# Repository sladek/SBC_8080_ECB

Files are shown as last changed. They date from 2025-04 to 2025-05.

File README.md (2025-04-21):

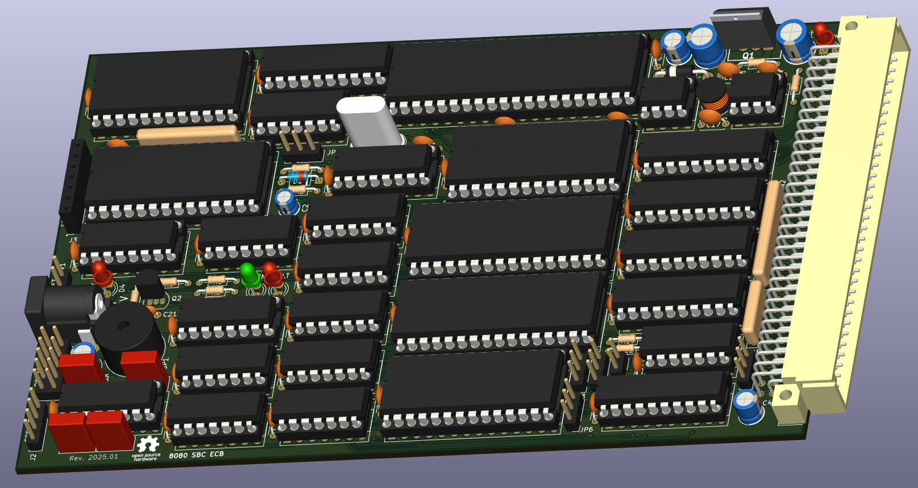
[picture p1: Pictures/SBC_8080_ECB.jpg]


## SBC 8080 ECB microcomputer

This is my attempt to build a single-board microcomputer based on the Intel 8080 CPU. It contains the following features:

- Extended 512k x 8-bit SRAM that can be fully accessed via paging.

- 128 x 8-bit FLASH EPROM that is accessible after RESET so it can contain a bootloader, which can be moved to SRAM and boot the operating system or monitor program.

- Programmable Interrupt Controller Intel 8259.

- Programmable Interval Timer Intel 8253, which is used for baud rate generation and can also generate an interrupt and be connected to the speaker.

- Universal Synchronous/Asynchronous Receiver/Transmitter (USART) Intel 8251 used as serial console so SBC can be accessed directly via RS232 interface.

- ECB bus interface, which can be used for microcomputer extensions. The ECB bus interface facilitates communication between the main processor and various peripheral devices, enabling system expansion and enhancing functionality. Additionally, it allows for the integration of specialized hardware components, which can further optimize performance and adaptability in various applications. History of ECB bus is described below.

- Voltage power supply for CPU: +5V, -5V, +12V which follows the requirement that -5V must be the first voltage present. It also contains inverter for -5V generation and a boost converter from 5V to 12V so the SBC can be powered only from one +5V power supply.

Here you can find a schematics for the SBC. Kicad files are also available in this repository. 
[SBC_8080_ECB schematics.](Documentation/SBC_8080_ECB_.pdf)

## ECB bus history

(https://www.retrobrewcomputers.org/doku.php?id=boards:ecb:start)

Below is an image depicting the latest definition of the ECB bus as utilized by the RetroBrew Computers group. It also addresses issues related to the /RESET and /RESOUT pin definitions and the solutions implemented. This design incorporates a 3-pin jumper header to allow for the selection of the appropriate configuration.

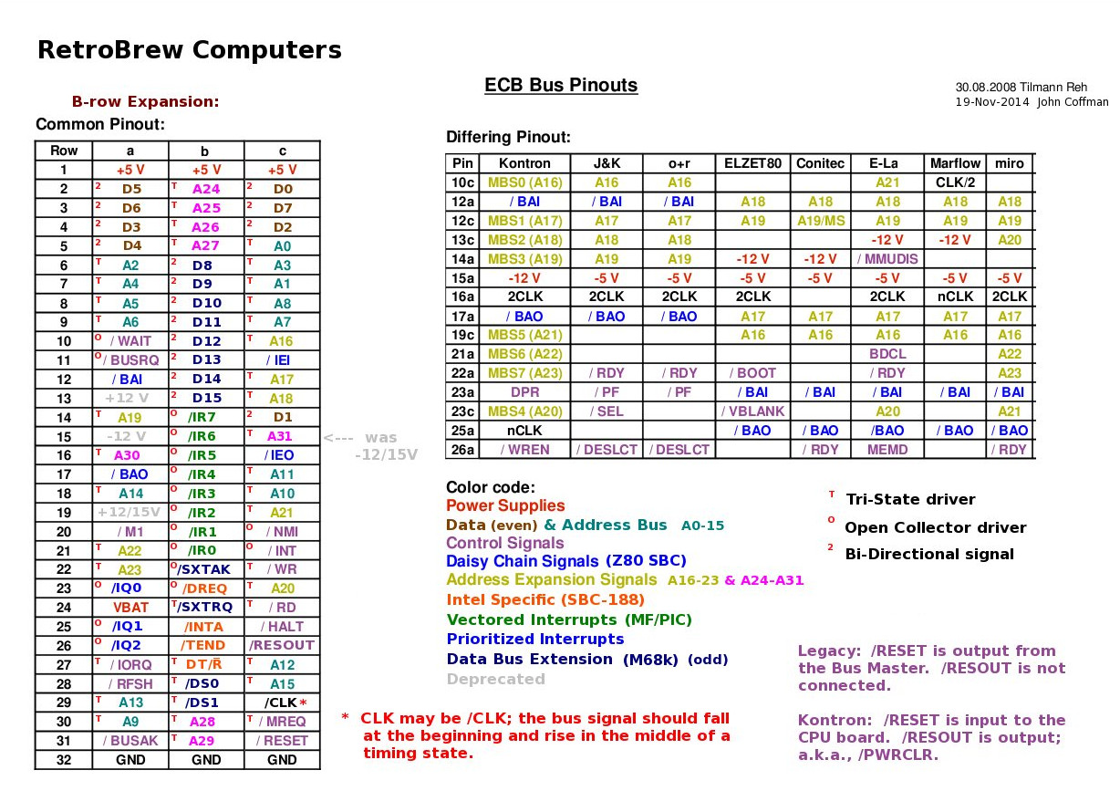
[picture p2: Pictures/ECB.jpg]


The German firm Kontron defined what is believed to be the earliest bus using the 96-pin DIN 41612 EuroCard connectors. The bus for their Z80 offering used only the A-row and C-row pins; the B-row was left entirely unused to allow for the use of 64-pin connectors in the 96-pin format.

The earliest known RetroBrew bus definition included B-row pin definitions to facilitate the anticipated expansion of the Z80 bus to other processors, particularly Intel. To this day, the ECB SBC v2 (Z80) does not use the B-row pins.

One error occurred in defining the first RetroBrew bus: confusion between signals RESET (C-31) and RESOUT (C-26). The error resulted in a bad guess at what Kontron's intentions were with these two signals. SBC v1 (Z80) used RESET as an output from the CPU board to peripheral boards and did not use the RESOUT signal at all. Peripheral boards were designed with this assumption. When it was pointed out several years ago (I am unsure of the date) that Kontron's intention was for RESET to be an input to the CPU board only and that the CPU board would then put out a signal, RESOUT, to all of the peripheral boards in the system.

The resolution to the above mistake is that all the newer CPU and peripheral boards have a reset selection jumper to select which RetroBrew reset convention is to be used. Look for a 3-pin jumper header: shorting pins 1-2 indicates the older, erroneous, reset convention for use with older boards; shorting pins 2-3 indicates the use of the Kontron convention. The Kontron convention is essential if RESET is to be received from any of the ECB backplanes, and only newer boards are allowed in such a system. Old CPU boards have a 2-pin Reset (in) connection as well as a reset switch right on the CPU card.

## Generate baud rate for 8251

### Response:

The **8253 Programmable Interval Timer (PIT)** can be used as a **baud rate generator** for serial communication by generating clock pulses at the required frequency. This is done by programming one of its three counters to divide an input clock signal down to the desired baud rate.

### Steps to Use 8253 as Baud Rate Generator

1. **Select the Counter:** 
   The 8253 has three counters (Counter 0, Counter 1, Counter 2). You need to choose one for generating the baud rate.

2. **Provide the Clock Input:**
   
   The 8253 typically receives a clock input (e.g., **1.8432 MHz or some
   other standard clock frequency**). Ensure the clock is stable and properly connected.

3. **Calculate the Divider Value:**  
   The baud rate is generated by dividing the input clock using a counter. The formula is:
   
    Input Frequency RateDivider=Baud RateClock Input Frequency
   
   For example, if the input clock is **1.8432 MHz** and you need a baud rate of **9600**,
   the divider value is:
   
   1843200÷9600=192

4. **Program the 8253:**
   
   - Load the
     appropriate **mode** (typically Mode 2 – Rate Generator or Mode 3 – Square Wave).
   
   - Load the **divider value** into the selected counter.
   
   - Start the timer and route its output to the serial communication hardware (like 8251 USART or UART).

5. **Connect Output to Serial**
   Device: The output of the **8253 counter** is connected to the baud rate clock input of a serial communication device like the **8251 USART** or a UART module.

### Example: Setting Baud rate for 9600 using 1.8432 MHz Clock

- Use **Counter 0** of **8253**.

- Program it in **Mode 2 (Rate Generator)**.

- Load **192** as the divider value.

#### **Programming Steps (for an x86-based system)**

Assembly code

```
    MOV AL, 34H    ; Control Word: Counter 0, Mode 2, LSB/MSB
    OUT 43H, AL    ; Send control word to 8253
    MOV AL, 192    ; Load LSB (Least Significant Byte)
    OUT 40H, AL    ; Send LSB to Counter 0
    MOV AL, 0      ; Load MSB (Most Significant Byte)
    OUT 40H, AL    ; Send MSB to Counter 0
```

- **43H** → Control port of **8253**

- **40H** → Counter 0 data port

### **Modes Used in 8253 for Baud Rate**

- **Mode 2 (Rate Generator)** → Outputs a
   frequency suitable for baud generation.

- **Mode 3 (Square Wave Generator)** → Outputs a symmetrical square wave (useful in some applications).

### **Final Connection**

The **OUT0** pin of **8253** (if using Counter 0) is connected to the **clock input** of **8251 USART or UART** for serial communication.

### **Summary**

- Use **Mode 2 (Rate Generator)**

- Compute the **divider value** using the formula

- Program the **control word and counter value**

- Connect **output** to the **serial device** clock input.

This setup allows the **8253** to act as a **baud rate generator** for serial communication.

## Baud rate divider

As crystal frequency is 18.432 Mhz and it is outputted from I8224, we can use that frequency to generate baud rate clock signal for I8251. Below is the solution.

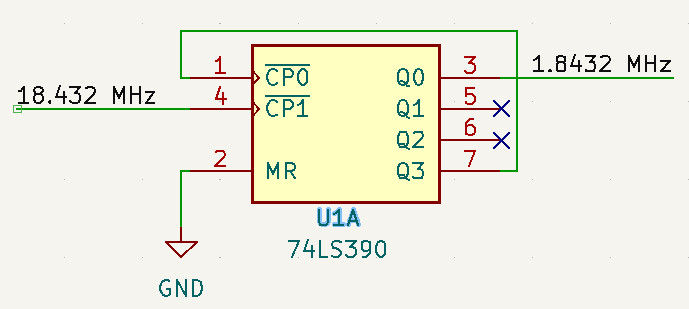
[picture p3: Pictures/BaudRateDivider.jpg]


74LS390 contains two decade counters, where /CP0 → Q0 functions as a divider by 2, and /CP1 → Q1, Q2, Q3 operates as a divider by 5. We send an 18.432 MHz clock signal from I8224 to /CP1; it is divided by 5 and then fed to /CP0, where it is divided by 2. This arrangement will generate a square signal with an exact 50% duty cycle. The output signal from Q0 is then fed to the I8252 timer, where the appropriate baud rate can be generated.

### Shadow FLASH select logic

In the picture below you can see shadow FLASH select logic schematics.

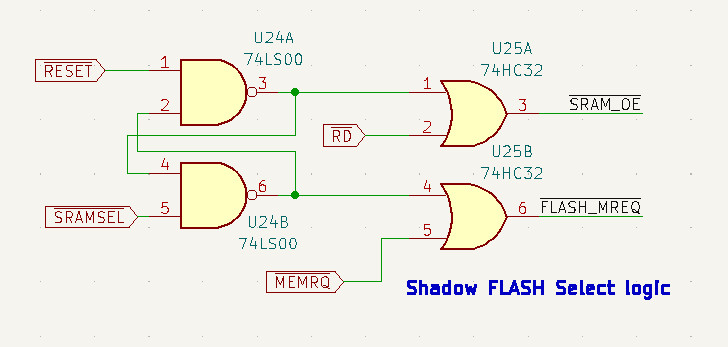
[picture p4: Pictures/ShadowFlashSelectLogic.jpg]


After /RESET (at this point, the /SRAMSELECT signal from the IO decoder is HIGH), /SRAM_SEL is HIGH and /FLASH_SEL is LOW. Now /SRAM_OE is HIGH (the DATA from RAM are in high impedance, although writing is not prohibited), so the /RD signal has no effect on /SRAM_OE. Only changes in /MEMRQ will impact the /FLASH_MREQ signal, which means that only FLASH memory can be accessed, either for reading or for writing. So it is also possible to flash the memory using a programmer connected to the ECB bus. A simulation has also been conducted in Verilog (via iVerilog) and can be seen below.

```
/*
 Test bench
*/

`timescale 10ns/10ns

module shadow_flash_select_logic_tb();

   reg MEMRQ, RESET, SRAMSEL, RD;
   wire SRAM_SEL, FLASH_SEL, SRAM_OE, FLASH_MEMRQ;

   initial begin
      $dumpfile ("shadow_flash_select_logic.vcd");
      $dumpvars;
   end

  initial begin
     RESET = 1;
     #10
     RESET = 0;
     #5
     RESET = 1;
  end

  initial begin
     SRAMSEL = 1;
     RD = 1;
     MEMRQ = 1;
  end

  initial begin
     #50;
       RD = 0;
     #50;
       RD = 1;
     #50;
       MEMRQ = 0;
     #50;
       MEMRQ = 1;
     #50
       SRAMSEL = 0;
     #50
       RD = 0;
     #50
       RD = 1;
     #50
       MEMRQ = 0;
     #50
       MEMRQ = 1;
 end

  initial begin
    #500;
    $finish;
  end

   // The Netlist
   nand(SRAM_SEL, RESET, FLASH_SEL);
   nand(FLASH_SEL, SRAMSEL, SRAM_SEL);
   or(SRAM_OE, SRAM_SEL, RD);
   or(FLASH_MREQ, FLASH_SEL, MEMRQ); 

endmodule
```

Simulation result in gtkwave is shown below.

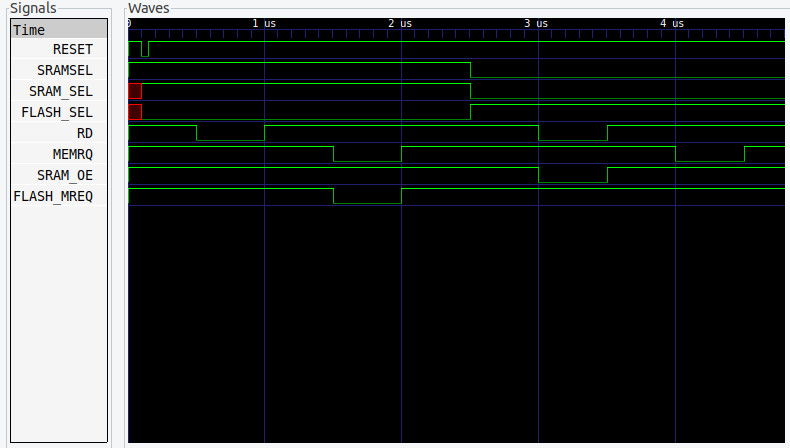
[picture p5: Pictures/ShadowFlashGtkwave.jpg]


### ECB bus data direction

As we also have to send and read data from the ECB bus, we have to make sure that bus data buffers are properly directed if there is a bus request (BUSRQ) from the bus itself.

Signal DATA_DIR Select the direction of the data buffer. If DATA_DIR is log 0, data direction is from the board to the ECB bus, and if DATA_DIR is log 1, 1data can flow from the ECB bus to the board.

This is done by the circuit below. Basically, the upper part (/MEMRQ, /RD, /IOSEL, which is low when internal peripherals are selected) takes care of standard operations, and the upper part is involved when there is a request from the ECB bus. (/RD, /BUSAK)

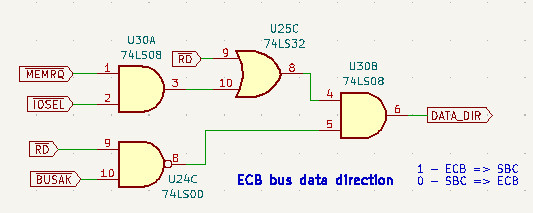
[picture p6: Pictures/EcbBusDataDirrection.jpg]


Below you can see simulation code and simulation result.

```
/*
 Test bench
*/

`timescale 10ns/10ns

module shadow_flash_select_logic_tb();

   reg MREQ, IOSEL, RD, BUSAK;
   wire DATA_DIR, MREQ_IOSEL, RD_BUSAK, DATAEN;

   initial begin
      $dumpfile ("ecb_data_dir_logic.vcd");
      $dumpvars;
   end

  initial begin
    MREQ = 1;
    IOSEL = 1;
    RD = 1;
    BUSAK = 1;
/* MREQ and RD */
    #50
      MREQ = 0;
    #10
      RD = 0;
    #50
      RD = 1;
    #10
      MREQ = 1;
/* IOSEL and RD */
    #50
      IOSEL = 0;
    #10
      RD = 0;
    #50
      RD = 1;
    #10
      IOSEL = 1;
/* BUSAK and RD */
    #50
      BUSAK = 0;
    #50
      BUSAK = 1;
    #50
      RD = 0;
    #50
      RD = 1;
  end

  initial begin
    #500;
    $finish;
  end

   // The Netlist
   and(MREQ_IOSEL, MREQ, IOSEL);
   nand(RD_BUSAK, RD, BUSAK);
   or(RD_MREQ_IOSEL, MREQ_IOSEL, RD);
   and(DATA_DIR, RD_MREQ_IOSEL, RD_BUSAK);

endmodule
```

And the simulation result is below.



### Peripherals address space

Internal peripherals are selected by the following decoder.

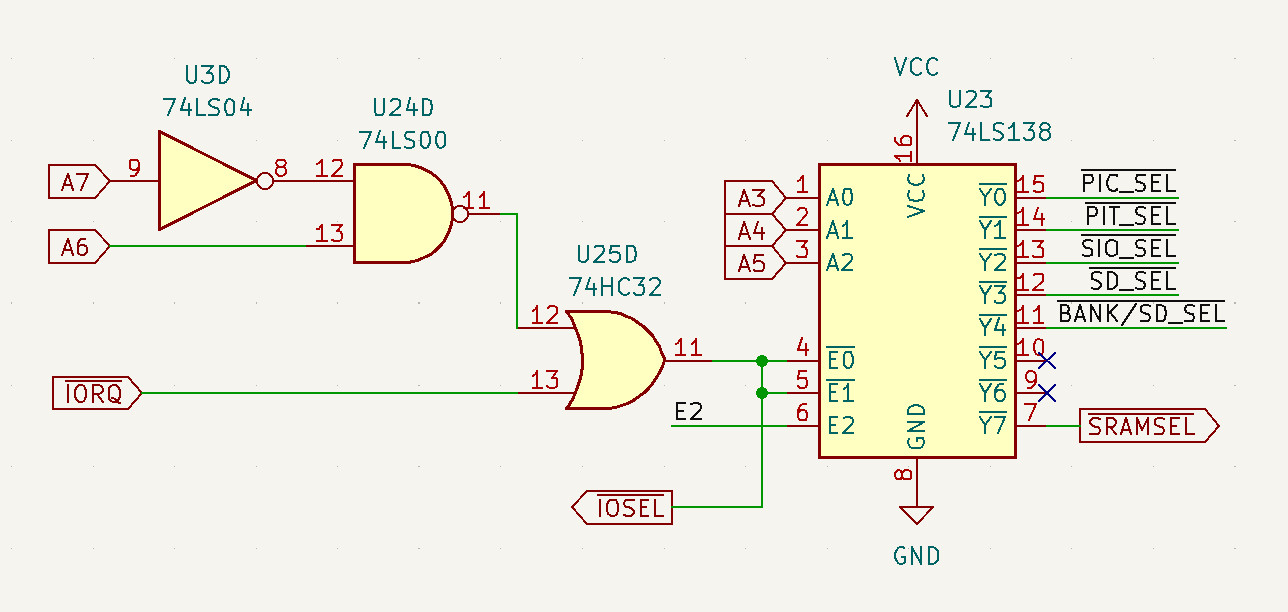
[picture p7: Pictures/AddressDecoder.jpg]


The address space with this circuit is 0x40 – 0x7f.

Where base addresses of peripherals are in the following table.

| | |
| --- | --- |
| Peripheral | Address range |
| PIC 8259A | 0x40 – 047 |
| PIT 8253 | 0x48 - 0x4F |
| SIO 8251 | 0x50 - 0x57 |
| RAM bank/ SD card select register (/BANK/SD_SEL ) | 0x58 - 0x5F |
| RAM select signal (/SRAMSEL) | 0x78 - 0x7F |

Below is verilog simulation result for the decoder.

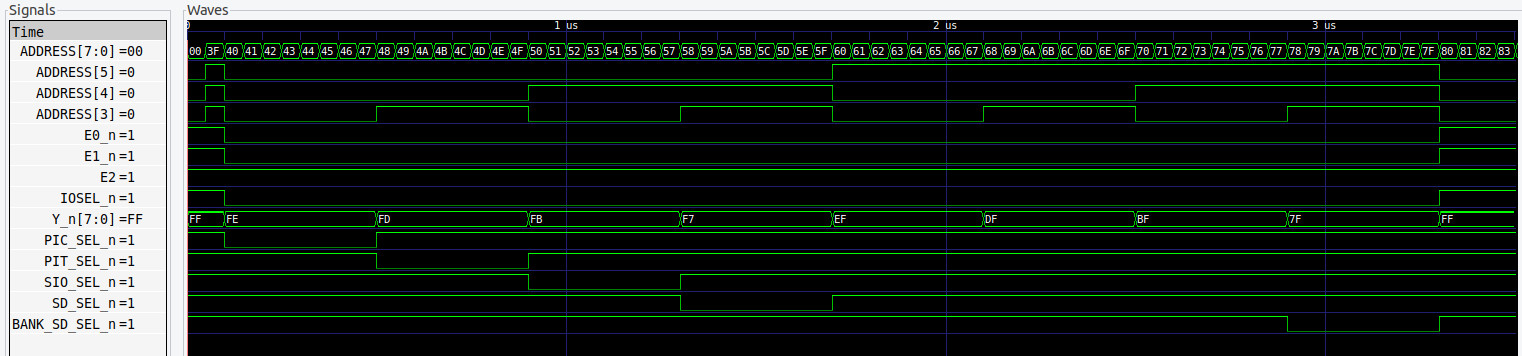
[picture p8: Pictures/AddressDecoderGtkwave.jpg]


And the source code. I intentionally use primitives for simulation of 74LS138 to prevent some simulation glitches I got when I tried to use behavioral modeling. It is quite simplified as I’ve just wanted to verify address space for peripherals.

```
/*
 Test bench
*/

`timescale 10ns/10ns

module SN74LS138(input [2:0] ADDR, input E0_n, E1_n, E2, output wire [7:0] Y_n);

  not(E2_n, E2);
  nor(ENBL, E2_n, E0_n, E1_n);
  not(A_n, ADDR[0]);
  not(B_n, ADDR[1]);
  not(C_n, ADDR[2]);
  not(A, A_n);
  not(B, B_n);
  not(C, C_n);
  nand(Y_n[0], A_n, B_n, C_n, ENBL);
  nand(Y_n[1], A, B_n, C_n, ENBL);
  nand(Y_n[2], A_n, B, C_n, ENBL);
  nand(Y_n[3], A, B, C_n, ENBL);
  nand(Y_n[4], A_n, B_n, C, ENBL);
  nand(Y_n[5], A, B_n, C, ENBL);
  nand(Y_n[6], A_n, B, C, ENBL);
  nand(Y_n[7], A, B, C, ENBL);

endmodule

module peripheral_decoder_tb();
  reg  [7:0] ADDRESS = 0;
  reg  A6, A7, IORQ_n;
  wire [7:0] OUT;
  wire A7_n, A7_A6, IOSEL_n, PIC_SEL_n, PIT_SEL_n, SIO_SEL_n, SD_SEL_n, BANK_SD_SEL_n;
  integer I = 0;

   initial begin
      $dumpfile ("peripheral_decoder.vcd");
      $dumpvars;
   end

  initial begin
    IORQ_n = 0;
    ADDRESS = 'h00;
    for ( I = 'h3F ; I < 'hff; I = I + 1) begin
      #5 ADDRESS = I;
    end

  end

  initial begin
    #350;
    $finish;
  end
  assign PIC_SEL_n = OUT[0];
  assign PIT_SEL_n = OUT[1];
  assign SIO_SEL_n = OUT[2];
  assign SD_SEL_n = OUT[3];
  assign BANK_SD_SEL_n = OUT[7];
  // The Netlist
  SN74LS138 ls138(ADDRESS[5:3], IOSEL_n, IOSEL_n, 1'b1 , OUT);
  not(A7_n, ADDRESS[7]);
  nand(A7_A6, A7_n, ADDRESS[6]);
  or(IOSEL_n, A7_A6, IORQ_n);
endmodule
```

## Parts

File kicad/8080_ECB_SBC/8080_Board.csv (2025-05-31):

Reference | Value | Qty | Mfr. No | DNP | Exclude from BOM | Exclude from Board
C4,C6,C7,C8,C9,C10,C11,C12,C13,C14,C15,C18,C20,C26,C27,C28,C29,C30,C31,C32,C33,C34,C35,C36,C37,C38,C39,C40,C41,C42,C43 | 0.1uF | 31 | SR215E104MAR
L1 | 33uF | 1 | SBC2-330-112
C1 | 39p | 1 | RDE5C1H390J0P1H03B
C21 | 0.01uF | 1 | RDE5C1H103J1S1H3A
C16 | 47uF | 1 | MAL214256479E3
C22,C23,C24,C25 | 1.0 uF | 4 | FK28X5R1E105K
C17,C19 | 1.0uF | 2 | FG28X7R1E105KRT06
C3,C5 | 470uF | 2 | ESK477M6R3AE3AA
C2 | 4u7 | 1 | ECE-A1CKN4R7I
C44,C45 | 220uF | 2 | ECA-0JHG221B
R5 | 33 | 1 | CF18JT1R00
R3,R7,R8 | 1k5 | 3 | CF18JT1K50
R6 | 1k | 1 | CF18JT1K00
R2 | 10 | 1 | CF18JT10R0
R10,R11 | 10k | 2 | CF18JT10K0
R4 | 100k | 1 | CF18JT10K0
R1 | 220k | 1 | CF18JT220K
R9 | 470 | 1 | CF18JT470R
SP1 | AT-1224-TWT-R | 1 | AT-1224-TWT-R
Y1 | 18,432MHz | 1 | AB-18.432MHZ-B2
RN2 | 10k | 1 | 4609X-101-103LF
RN3 | 10k | 1 | 4608X-101-103FLF
RN1 | 10k | 1 | 4605X-101-103LF
JP2,JP3,JP4,JP6 | Jumper_3_Bridged12 | 4 | 22-28-4030
JP1 | Jumper_3_Bridged23 | 1 | 22-28-4030
J1 | +5V/5A | 1 | 694106301002
D4 | DISK | 1 | 3RDL-S
D3 | +5VP | 1 | 3RDL-S
D2 | HALT | 1 | 3RDL-S
D5 | RUN | 1 | 3GDL-S
U29 | SST39SF010 | 1
U28 | AS6C4008-55PCN | 1
U25,U27 | 74LS32 | 2
U24 | 74LS00 | 1
U23 | 74LS138 | 1
U22 | 74HC374 | 1
U21 | MAX232 | 1
U20 | 8251 | 1
U19 | 8259A | 1
U18 | 8253 | 1
U17 | 74LS390 | 1
U16 | 74LS240 | 1
U15 | 74LS244 | 1
U13 | 74LS243 | 1
U11,U12,U14 | 74LS245 | 3
U10 | C96ABC | 1
U9 | TC7660H | 1
U7 | LT1109A | 1
U5 | 8080A | 1
U4 | 74LS74 | 1
U3 | 74LS04 | 1
U2,U6 | 74LS125 | 2
U1,U30 | 74LS08 | 2
SW1 | RESET | 1
Q2 | PN2222A | 1
Q1 | IRF4905LPBF | 1
JP5 | Bank0/Bank1 | 1
J4 | RS232 | 1
J3 | Conn_01x07 | 1
J2 | SPEAKER | 1
IC2 | 8228 | 1
IC1 | 8224 | 1
D6 | 1N5818 | 1
D1 | 1N4148 | 1

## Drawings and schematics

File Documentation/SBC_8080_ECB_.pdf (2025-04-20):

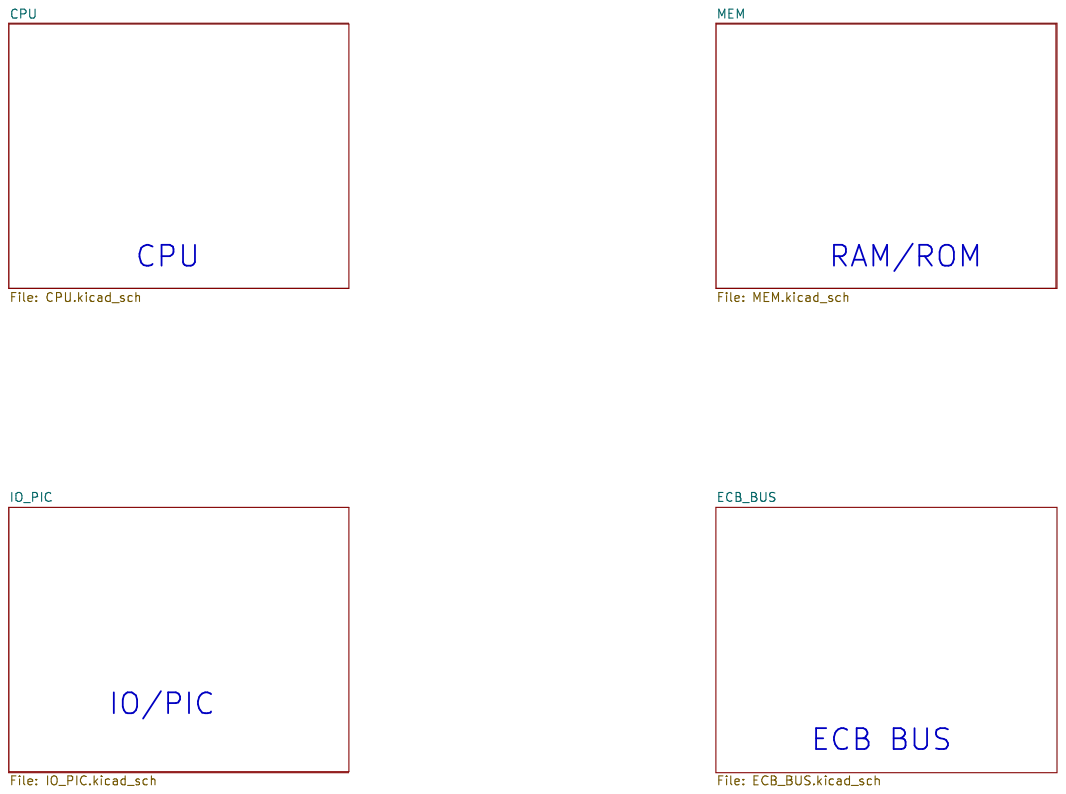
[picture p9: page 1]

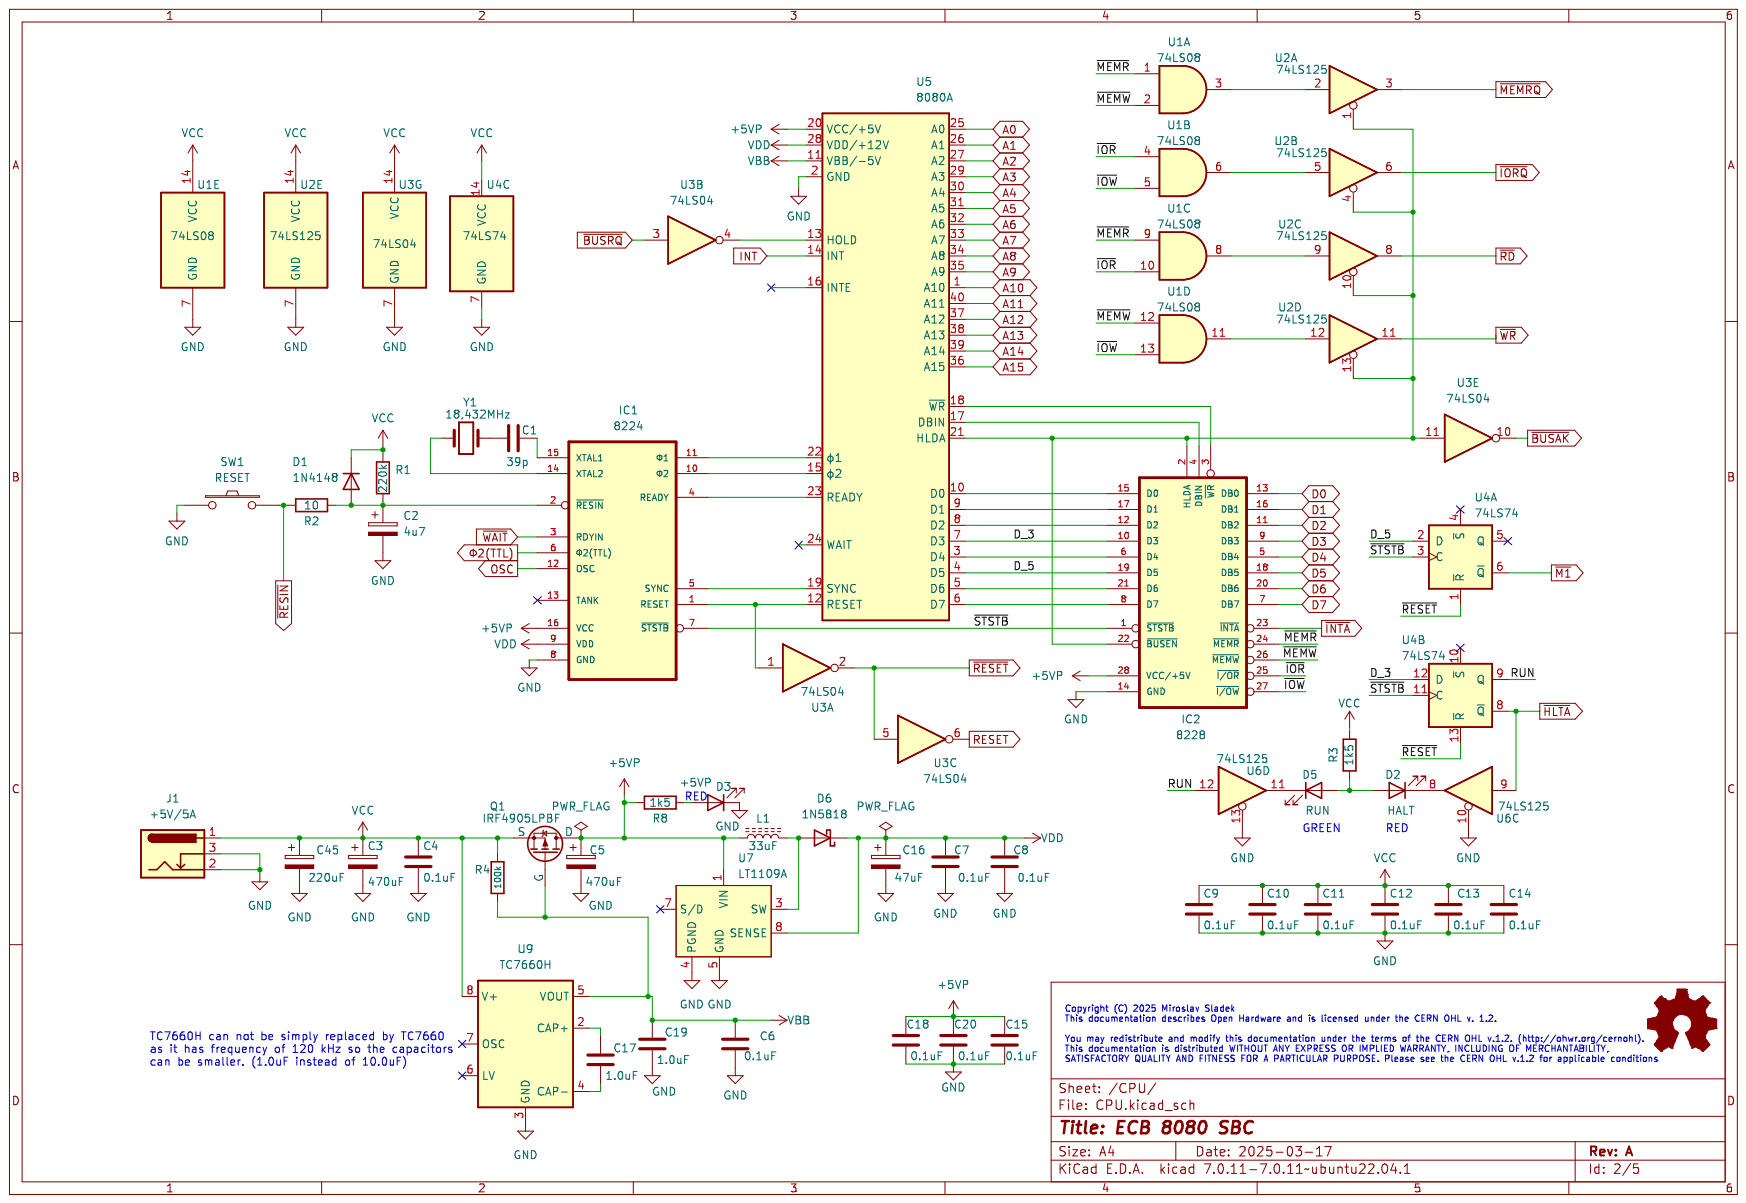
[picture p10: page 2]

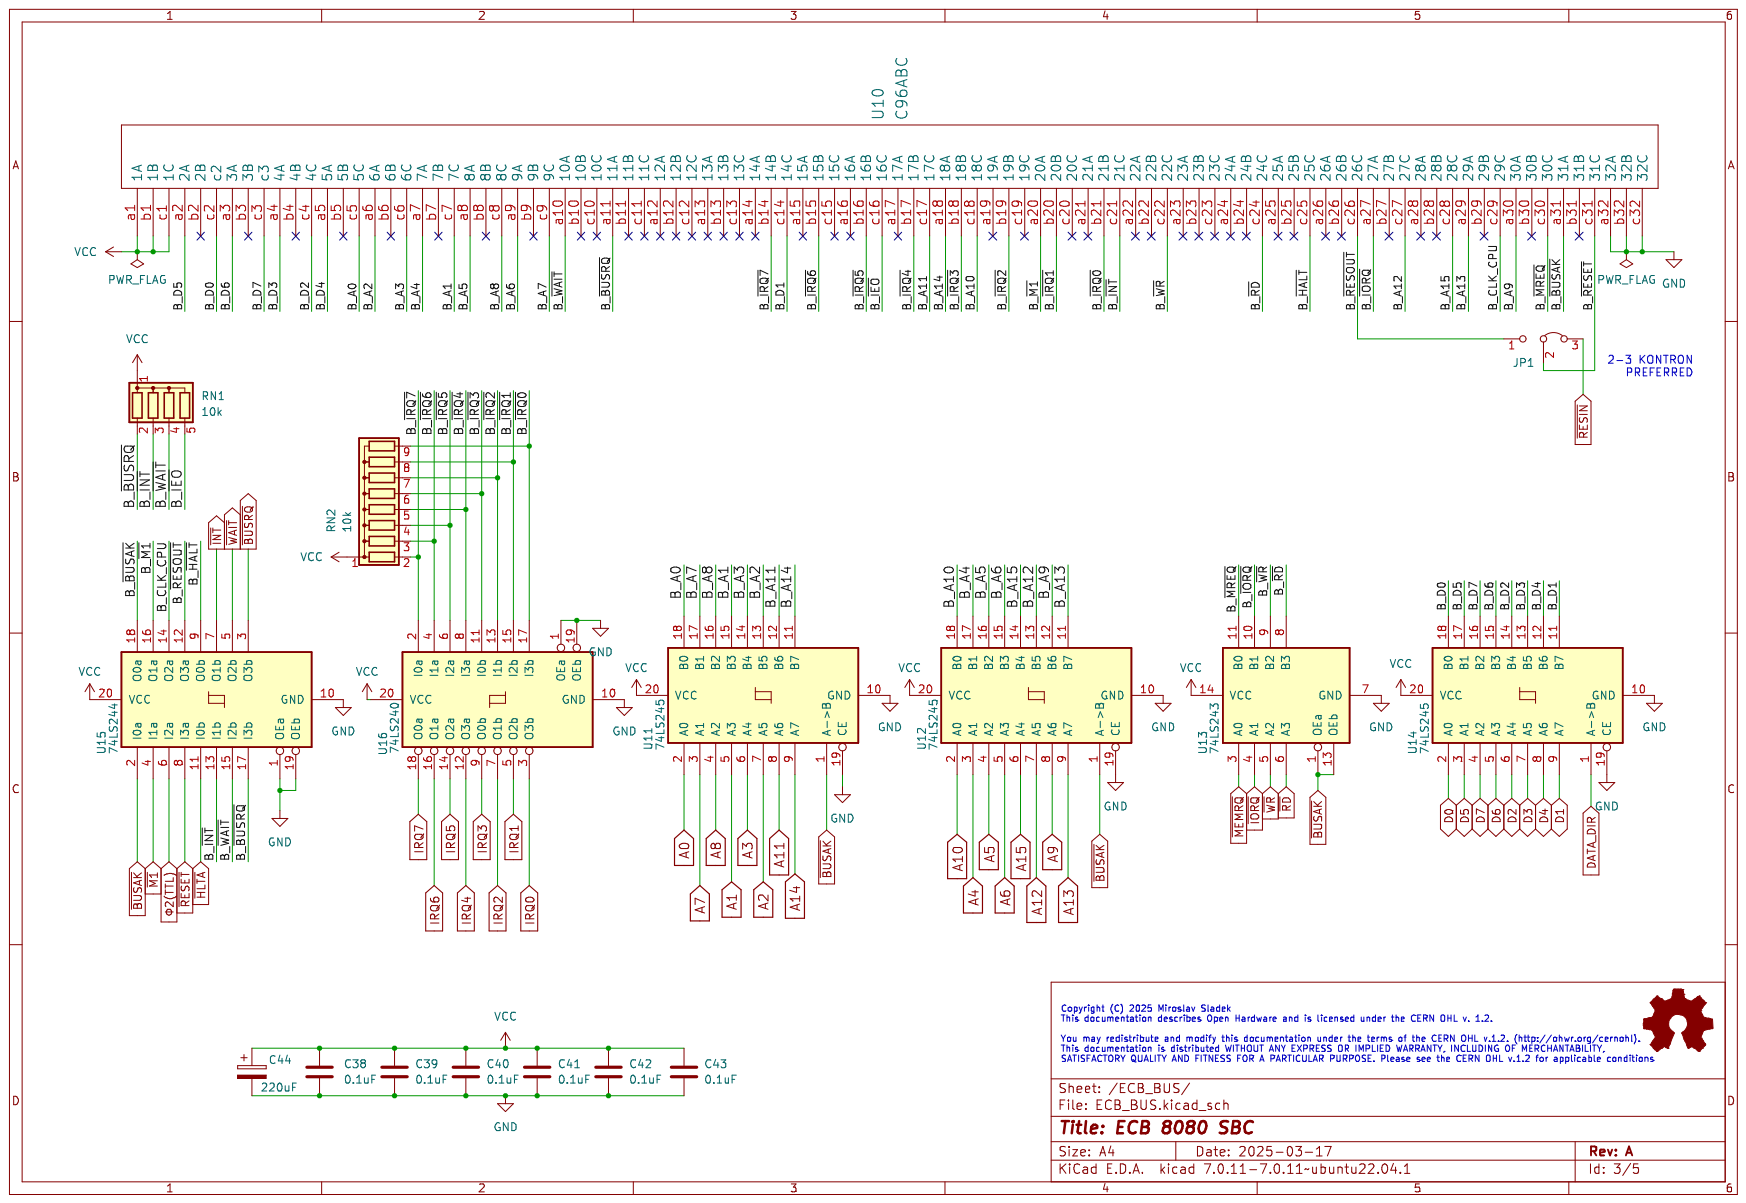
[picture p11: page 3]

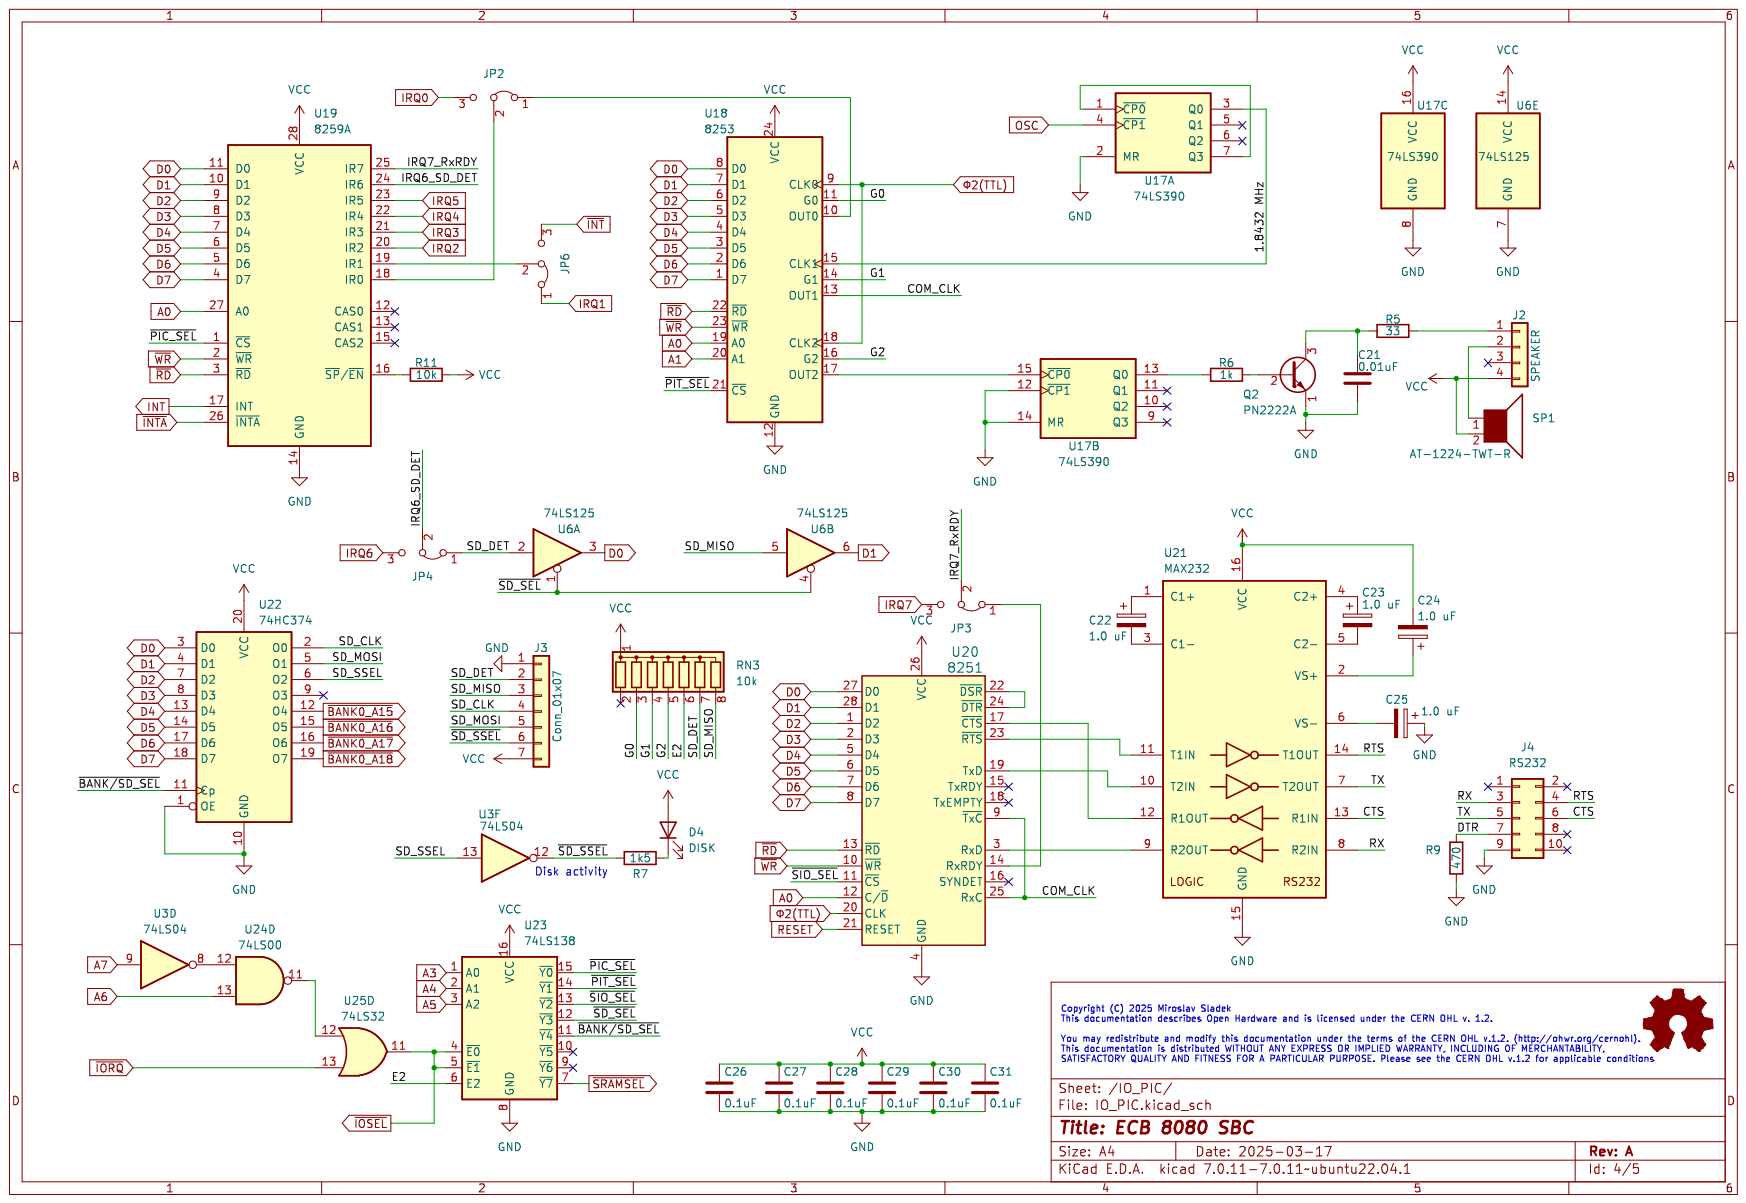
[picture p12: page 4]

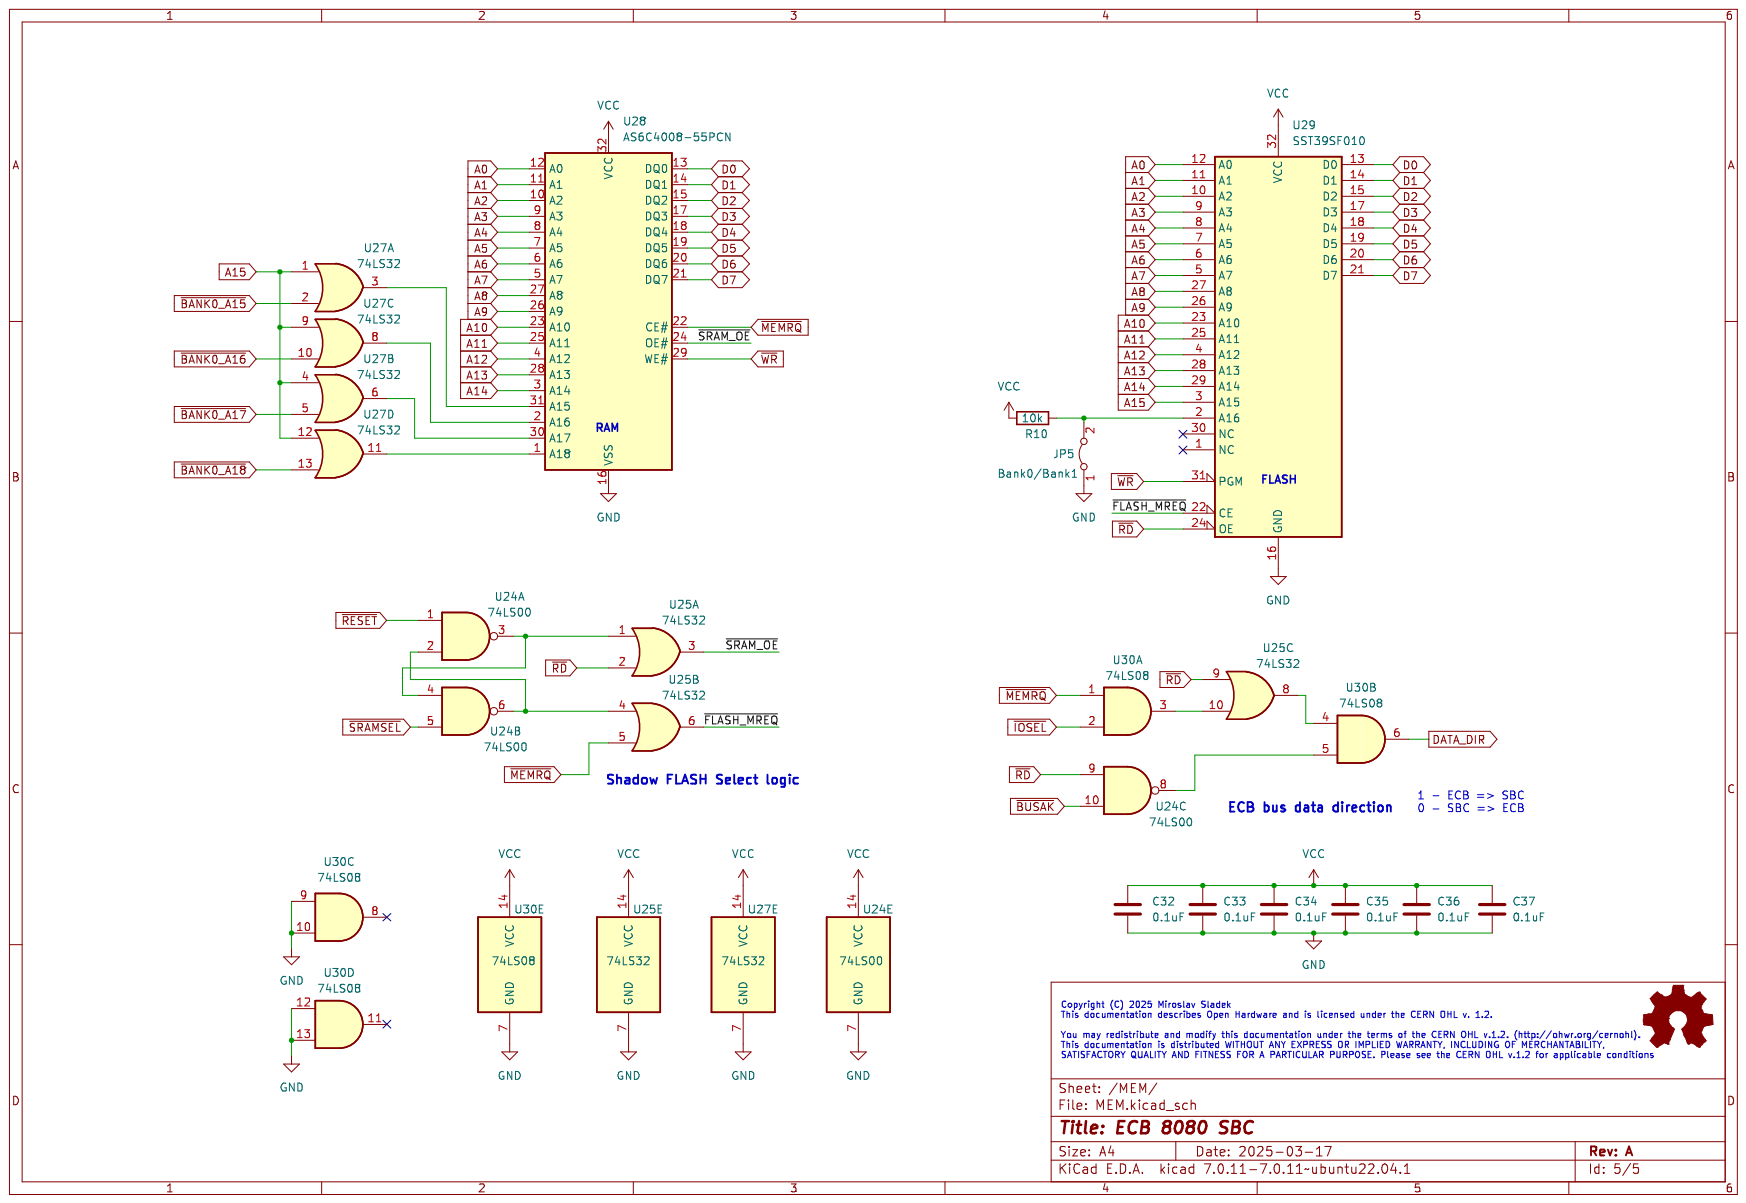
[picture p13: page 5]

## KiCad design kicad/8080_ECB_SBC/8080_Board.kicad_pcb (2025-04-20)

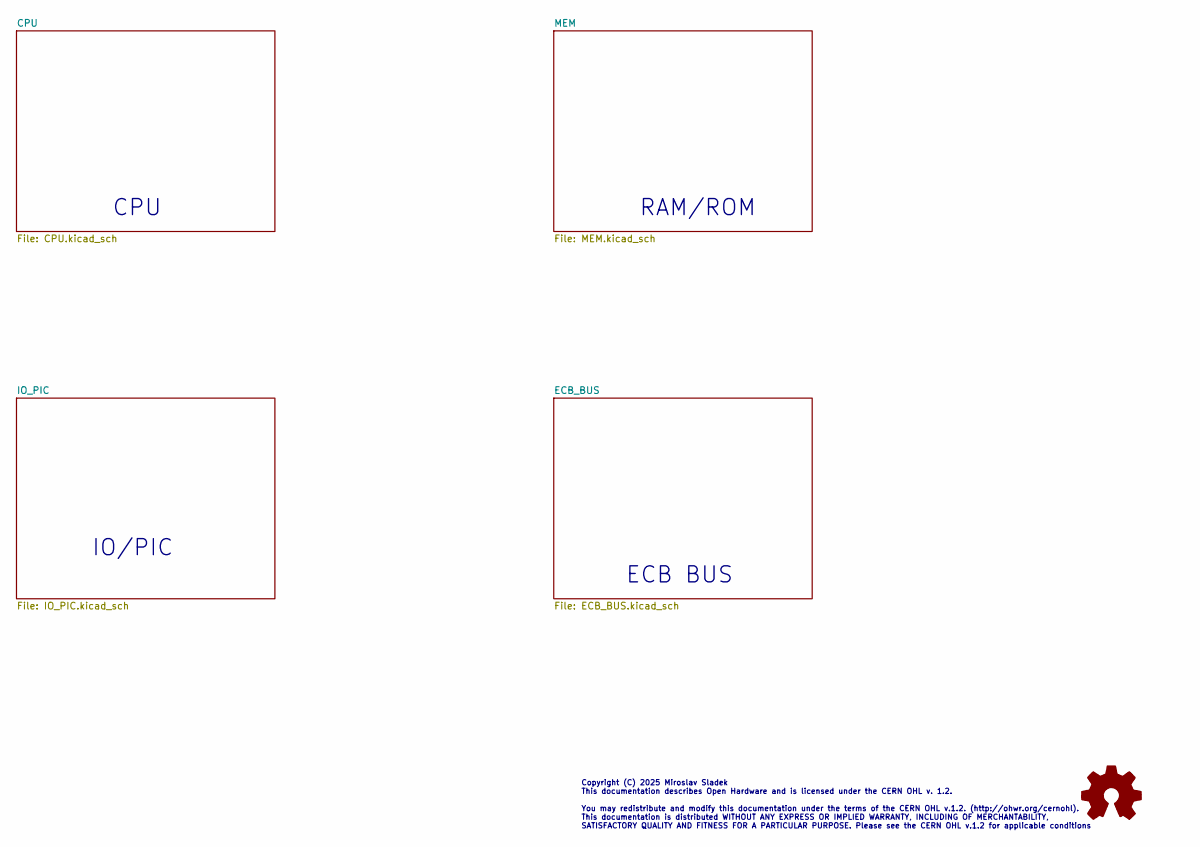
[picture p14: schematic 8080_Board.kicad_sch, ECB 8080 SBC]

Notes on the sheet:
RAM/ROM
IO/PIC
CPU
ECB BUS
Copyright (C) 2025 Miroslav Sladek This documentation describes Open Hardware and is licensed under the CERN OHL v. 1.2. You may redistribute and modify this documentation under the terms of the CERN OHL v.1.2. (http://ohwr.org/cernohl). This documentation is distributed WITHOUT ANY EXPRESS OR IMPL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

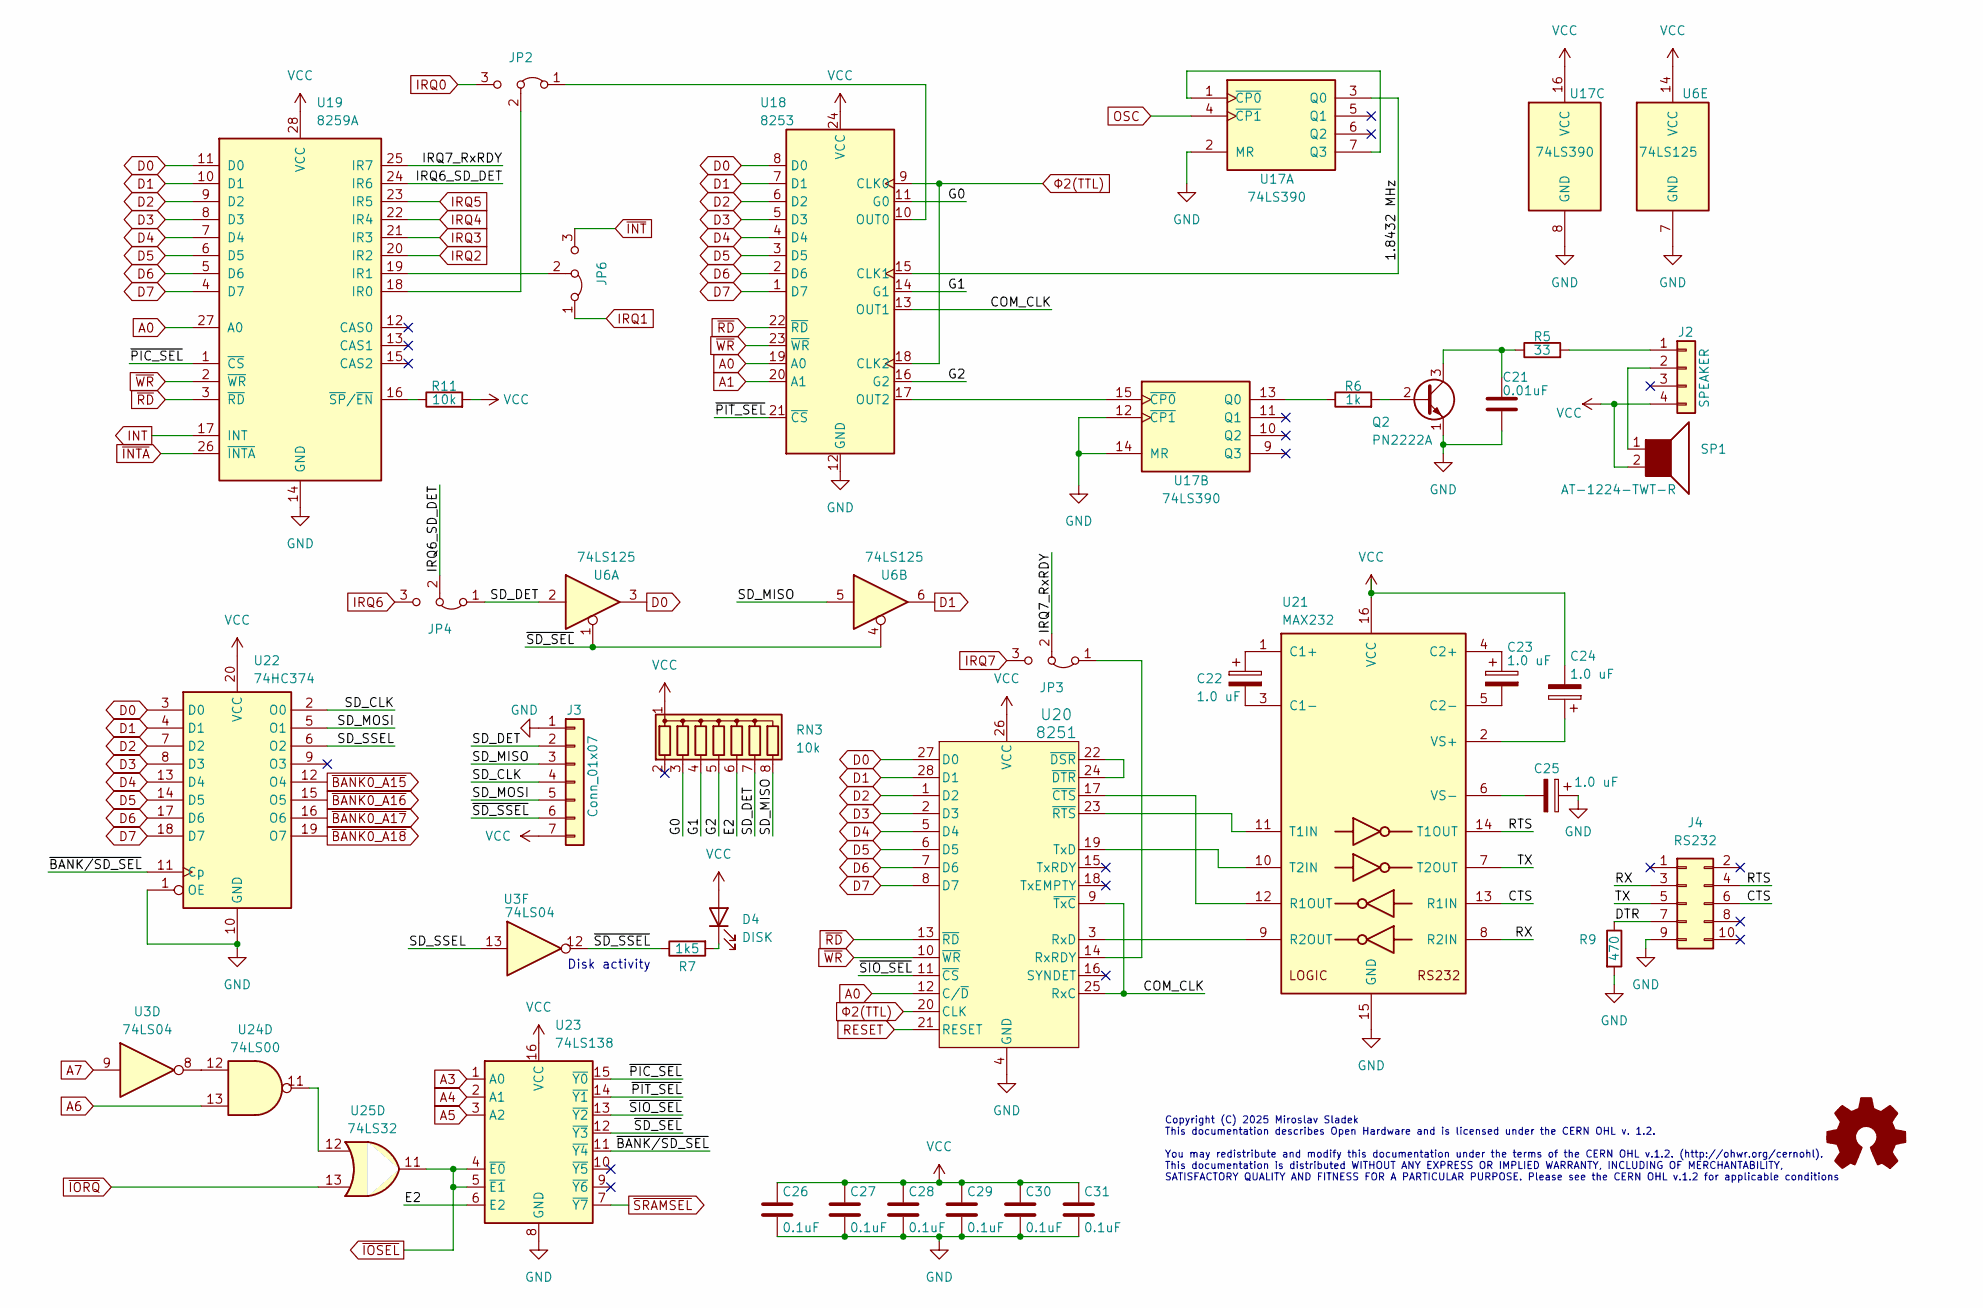
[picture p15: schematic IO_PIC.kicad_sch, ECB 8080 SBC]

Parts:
C21: 0.01uF; C_Disc_D3.0mm_W1.6mm_P2.50mm
C22, C23, C24, C25: 1.0 uF; C_Rect_L7.2mm_W3.0mm_P5.00mm_FKS2_FKP2_MKS2_MKP2
C26, C27, C28, C29, C30, C31: 0.1uF; C_Disc_D4.3mm_W1.9mm_P5.00mm
D4: DISK; LED_D3.0mm
J2: SPEAKER; PinHeader_1x04_P2.54mm_Vertical
J3: Conn_01x07; PinSocket_1x07_P2.54mm_Vertical
J4: RS232; PinHeader_2x05_P2.54mm_Vertical
JP2, JP3, JP4, JP6: Jumper_3_Bridged12; PinHeader_1x03_P2.54mm_Vertical
Q2: PN2222A; TO-92_Inline
R5: 33; R_Axial_DIN0204_L3.6mm_D1.6mm_P7.62mm_Horizontal
R6: 1k; R_Axial_DIN0204_L3.6mm_D1.6mm_P7.62mm_Horizontal
R7: 1k5; R_Axial_DIN0204_L3.6mm_D1.6mm_P7.62mm_Horizontal
R9: 470; R_Axial_DIN0204_L3.6mm_D1.6mm_P7.62mm_Horizontal
R11: 10k; R_Axial_DIN0204_L3.6mm_D1.6mm_P7.62mm_Horizontal
RN3: 10k; R_Array_SIP8
SP1: AT-1224-TWT-R; MagneticBuzzer_ProSignal_ABT-410-RC
U3: 74LS04; DIP-14_W7.62mm_Socket
U6: 74LS125; DIP-14_W7.62mm_Socket
U17: 74LS390; DIP-16_W7.62mm_Socket
U18: 8253; DIP-24_W15.24mm_Socket
U19: 8259A; DIP-28_W15.24mm_Socket
U20: 8251; DIP-28_W15.24mm_Socket
U21: MAX232; DIP-16_W7.62mm_Socket
U22: 74HC374; DIP-20_W7.62mm_Socket
U23: 74LS138; DIP-16_W7.62mm_Socket
U24: 74LS00; DIP-14_W7.62mm_Socket
U25: 74LS32; DIP-14_W7.62mm_Socket

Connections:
/IO_PIC/1.8432 MHz: U17.3 (Q0), U18.15 (CLK1)
/IO_PIC/COM_CLK: U18.13 (OUT1), U20.9 (~TxC), U20.25 (RxC)
/IO_PIC/CTS: J4.6, U21.13 (R1IN)
/IO_PIC/DTR: J4.7, R9.1
/IO_PIC/E2: RN3.6 (R5), U23.6 (E2)
/IO_PIC/G0: RN3.3 (R2), U18.11 (G0)
/IO_PIC/G1: RN3.4 (R3), U18.14 (G1)
/IO_PIC/G2: RN3.5 (R4), U18.16 (G2)
/IO_PIC/IRQ6_SD_DET: JP4.2 (C), U19.24 (IR6)
/IO_PIC/IRQ7_RxRDY: JP3.2 (C), U19.25 (IR7)
/IO_PIC/RTS: J4.4, U21.14 (T1OUT)
/IO_PIC/RX: J4.3, U21.8 (R2IN)
/IO_PIC/SD_CLK: J3.4, U22.2 (O0)
/IO_PIC/SD_DET: J3.2, JP4.1 (A), RN3.7 (R6), U6.2
/IO_PIC/SD_MISO: J3.3, RN3.8 (R7), U6.5
/IO_PIC/SD_MOSI: J3.5, U22.5 (O1)
/IO_PIC/SD_SSEL: U3.13, U22.6 (O2)
/IO_PIC/TX: J4.5, U21.7 (T2OUT)
/IO_PIC/~BANK/SD_SEL: U22.11 (Cp), U23.11 (~Y4)
/IO_PIC/~PIC_SEL: U19.1 (~CS), U23.15 (~Y0)
/IO_PIC/~PIT_SEL: U18.21 (~CS), U23.14 (~Y1)
/IO_PIC/~SD_SEL: U6.1, U6.4, U23.12 (~Y3)
/IO_PIC/~SD_SSEL: J3.6, R7.1, U3.12
/IO_PIC/~SIO_SEL: U20.11 (~CS), U23.13 (~Y2)
A0: U18.19 (A0), U19.27 (A0), U20.12 (C/~D); also elsewhere on the board
A1: U18.20 (A1); also elsewhere on the board
A3: U23.1 (A0); also elsewhere on the board
A4: U23.2 (A1); also elsewhere on the board
A5: U23.3 (A2); also elsewhere on the board
A6: U24.13; also elsewhere on the board
A7: U3.9; also elsewhere on the board
D0: U6.3, U18.8 (D0), U19.11 (D0), U20.27 (D0), U22.3 (D0); also elsewhere on the board
D1: U6.6, U18.7 (D1), U19.10 (D1), U20.28 (D1), U22.4 (D1); also elsewhere on the board
D2: U18.6 (D2), U19.9 (D2), U20.1 (D2), U22.7 (D2); also elsewhere on the board
D3: U18.5 (D3), U19.8 (D3), U20.2 (D3), U22.8 (D3); also elsewhere on the board
D4: U18.4 (D4), U19.7 (D4), U20.5 (D4), U22.13 (D4); also elsewhere on the board
D5: U18.3 (D5), U19.6 (D5), U20.6 (D5), U22.14 (D5); also elsewhere on the board
D6: U18.2 (D6), U19.5 (D6), U20.7 (D6), U22.17 (D6); also elsewhere on the board
D7: U18.1 (D7), U19.4 (D7), U20.8 (D7), U22.18 (D7); also elsewhere on the board
INT: U19.17 (INT); also elsewhere on the board
IRQ0: JP2.3 (B); also elsewhere on the board
IRQ1: JP6.1 (A); also elsewhere on the board
IRQ2: U19.20 (IR2); also elsewhere on the board
IRQ3: U19.21 (IR3); also elsewhere on the board
IRQ4: U19.22 (IR4); also elsewhere on the board
IRQ5: U19.23 (IR5); also elsewhere on the board
IRQ6: JP4.3 (B); also elsewhere on the board
IRQ7: JP3.3 (B); also elsewhere on the board
unnamed: D4.1 (K), R7.2
unnamed: J2.1, R5.2
unnamed: J2.2, SP1.1
unnamed: JP2.1 (A), U18.10 (OUT0)
unnamed: JP2.2 (C), U19.18 (IR0)
unnamed: JP3.1 (A), U20.14 (RxRDY)
unnamed: JP6.2 (C), U19.19 (IR1)
unnamed: Q2.2 (B), R6.2
unnamed: C21.1, Q2.3 (C), R5.1
unnamed: U17.1 (~CP0), U17.7 (Q3)
unnamed: R6.1, U17.13 (Q0)
unnamed: U17.15 (~CP0), U18.17 (OUT2)
unnamed: R11.1, U19.16 (~SP/~EN)
unnamed: U20.3 (RxD), U21.9 (R2OUT)
unnamed: U20.19 (TxD), U21.10 (T2IN)
unnamed: U20.17 (~CTS), U21.12 (R1OUT)
unnamed: U20.22 (~DSR), U20.24 (~DTR)
unnamed: U20.23 (~RTS), U21.11 (T1IN)
unnamed: C22.1, U21.1 (C1+)
unnamed: C22.2, U21.3 (C1-)
unnamed: C23.1, U21.4 (C2+)
unnamed: C23.2, U21.5 (C2-)
unnamed: C24.1, U21.2 (VS+)
unnamed: C25.2, U21.6 (VS-)
unnamed: U24.11, U25.12
unnamed: U3.8, U24.12
OSC: U17.4 (~CP1); also elsewhere on the board
RESET: U20.21 (RESET); also elsewhere on the board
VCC: C24.2, C26.1, C27.1, C28.1, C29.1, C30.1, C31.1, D4.2 (A), J2.4, J3.7, R11.2, RN3.1 (common), SP1.2, U6.14 (VCC), U17.16 (VCC), U18.24 (VCC), U19.28 (VCC), U20.26 (VCC), U21.16 (VCC), U22.20 (VCC), U23.16 (VCC); also elsewhere on the board
~BANK0_A15: U22.12 (O4); also elsewhere on the board
~BANK0_A16: U22.15 (O5); also elsewhere on the board
~BANK0_A17: U22.16 (O6); also elsewhere on the board
~BANK0_A18: U22.19 (O7); also elsewhere on the board
~INTA: U19.26 (~INTA); also elsewhere on the board
~INT: JP6.3 (B); also elsewhere on the board
~IORQ: U25.13; also elsewhere on the board
~IOSEL: U23.4 (~E0), U23.5 (~E1), U25.11; also elsewhere on the board
~RD: U18.22 (~RD), U19.3 (~RD), U20.13 (~RD); also elsewhere on the board
~SRAMSEL: U23.7 (~Y7); also elsewhere on the board
~WR: U18.23 (~WR), U19.2 (~WR), U20.10 (~WR); also elsewhere on the board
Φ2(TTL): U18.9 (CLK0), U18.18 (CLK2), U20.20 (CLK); also elsewhere on the board

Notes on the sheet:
Disk activity
Copyright (C) 2025 Miroslav Sladek This documentation describes Open Hardware and is licensed under the CERN OHL v. 1.2. You may redistribute and modify this documentation under the terms of the CERN OHL v.1.2. (http://ohwr.org/cernohl). This documentation is distributed WITHOUT ANY EXPRESS OR IMPL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

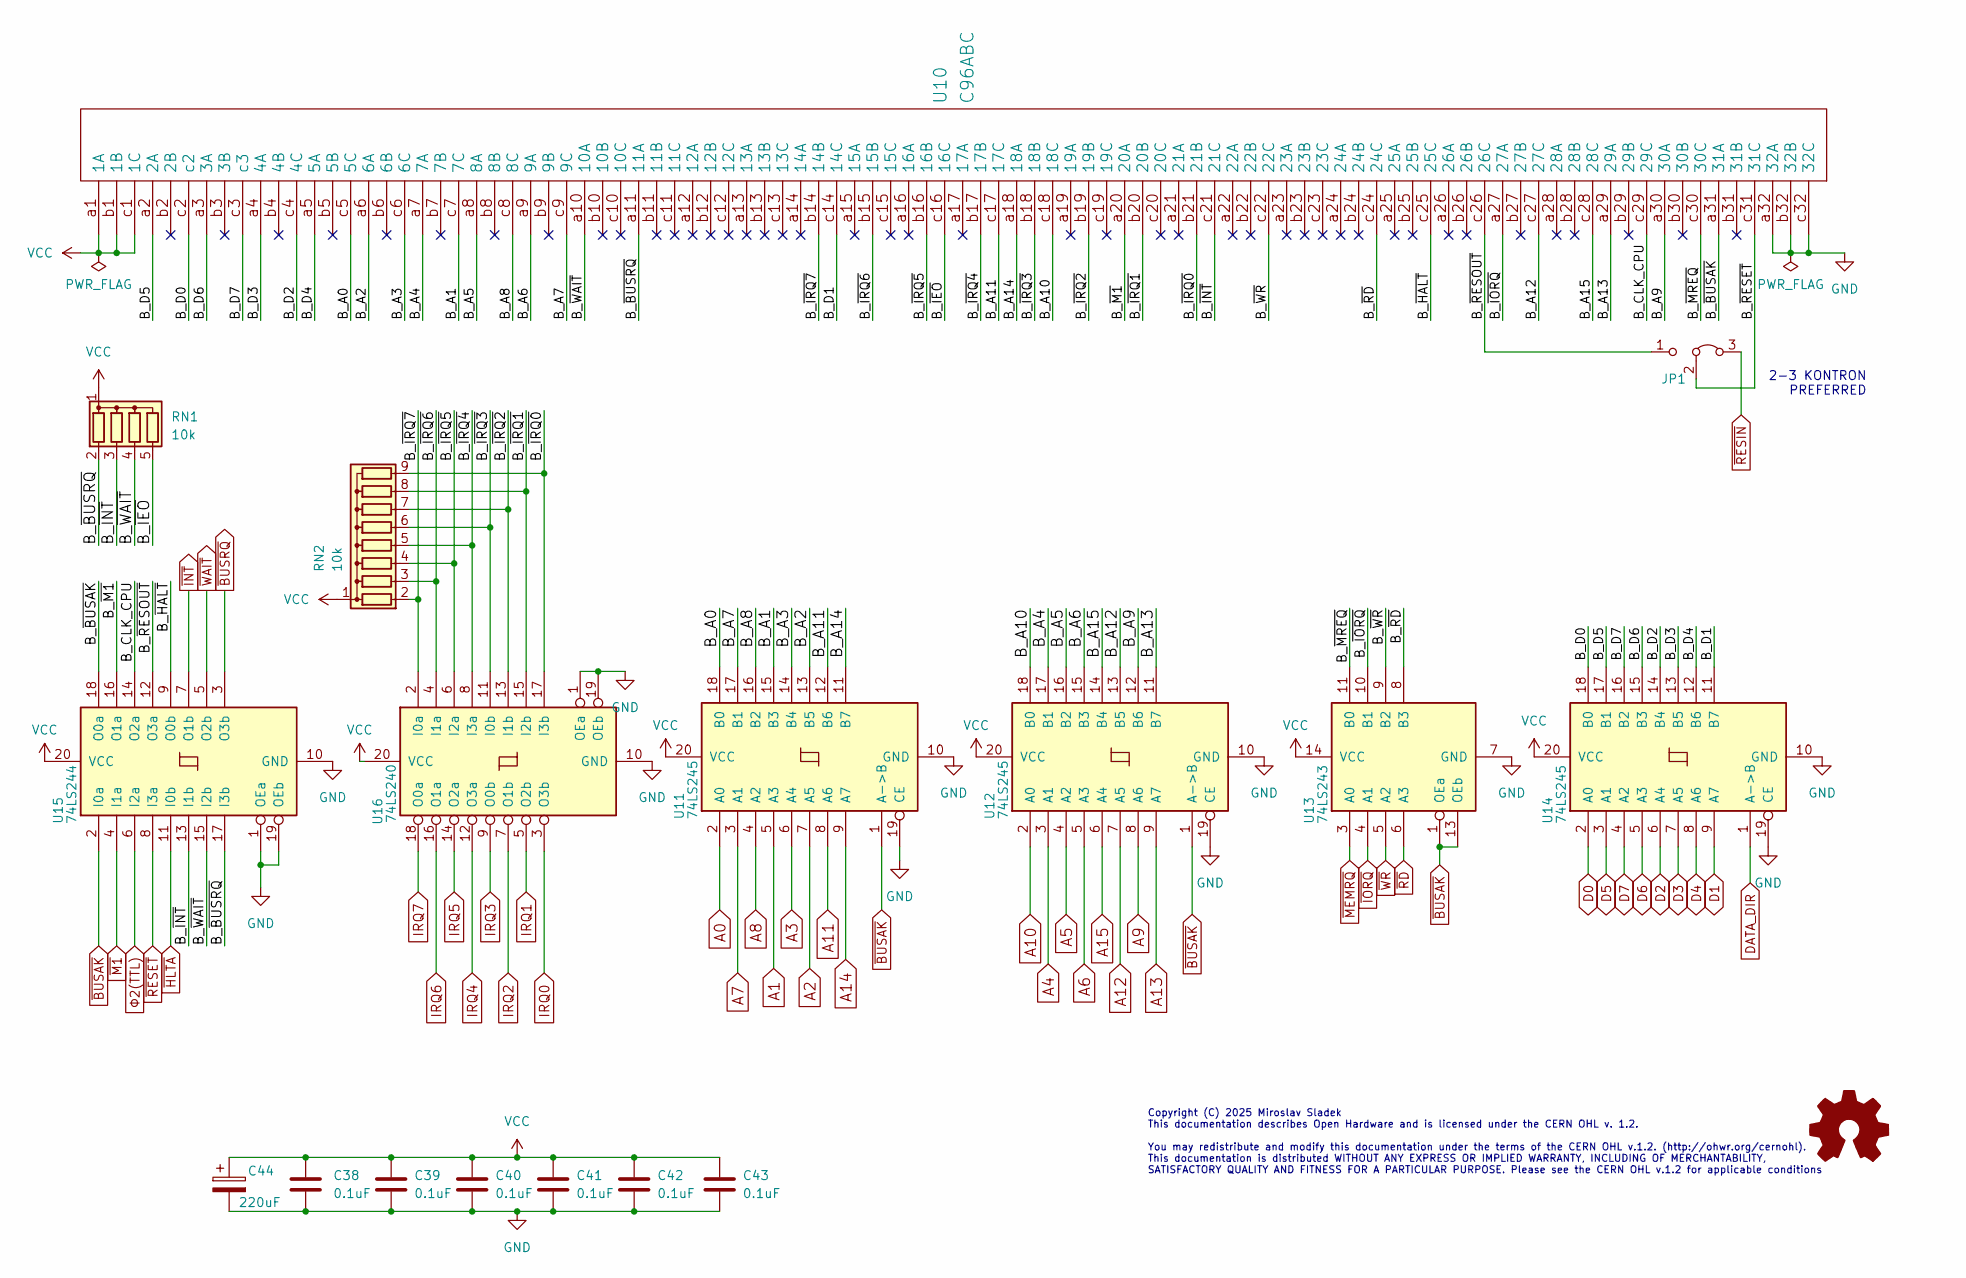
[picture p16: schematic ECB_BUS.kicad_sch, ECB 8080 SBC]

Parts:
C38, C39, C40, C41, C42, C43: 0.1uF; C_Disc_D4.3mm_W1.9mm_P5.00mm
C44: 220uF; CP_Radial_D5.0mm_P2.00mm
JP1: Jumper_3_Bridged23; PinHeader_1x03_P2.54mm_Vertical
RN1: 10k; R_Array_SIP5
RN2: 10k; R_Array_SIP9
U10: C96ABC; DIN41612_C_3x32_Male_Horizontal_THT
U11, U12, U14: 74LS245; DIP-20_W7.62mm_Socket
U13: 74LS243; DIP-14_W7.62mm_Socket
U15: 74LS244; DIP-20_W7.62mm_Socket
U16: 74LS240; DIP-20_W7.62mm_Socket

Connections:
/ECB_BUS/B_A0: U10.c5 (5C), U11.18 (B0)
/ECB_BUS/B_A1: U10.c7 (7C), U11.15 (B3)
/ECB_BUS/B_A2: U10.a6 (6A), U11.13 (B5)
/ECB_BUS/B_A3: U10.c6 (6C), U11.14 (B4)
/ECB_BUS/B_A4: U10.a7 (7A), U12.17 (B1)
/ECB_BUS/B_A5: U10.a8 (8A), U12.16 (B2)
/ECB_BUS/B_A6: U10.a9 (9A), U12.15 (B3)
/ECB_BUS/B_A7: U10.c9 (9C), U11.17 (B1)
/ECB_BUS/B_A8: U10.c8 (8C), U11.16 (B2)
/ECB_BUS/B_A9: U10.a30 (30A), U12.12 (B6)
/ECB_BUS/B_A10: U10.c18 (18C), U12.18 (B0)
/ECB_BUS/B_A11: U10.c17 (17C), U11.12 (B6)
/ECB_BUS/B_A12: U10.c27 (27C), U12.13 (B5)
/ECB_BUS/B_A13: U10.a29 (29A), U12.11 (B7)
/ECB_BUS/B_A14: U10.a18 (18A), U11.11 (B7)
/ECB_BUS/B_A15: U10.c28 (28C), U12.14 (B4)
/ECB_BUS/B_CLK_CPU: U10.c29 (29C), U15.14 (O2a)
/ECB_BUS/B_D0: U10.c2, U14.18 (B0)
/ECB_BUS/B_D1: U10.c14 (14C), U14.11 (B7)
/ECB_BUS/B_D2: U10.c4 (4C), U14.14 (B4)
/ECB_BUS/B_D3: U10.a4 (4A), U14.13 (B5)
/ECB_BUS/B_D4: U10.a5 (5A), U14.12 (B6)
/ECB_BUS/B_D5: U10.a2 (2A), U14.17 (B1)
/ECB_BUS/B_D6: U10.a3 (3A), U14.15 (B3)
/ECB_BUS/B_D7: U10.c3, U14.16 (B2)
/ECB_BUS/B_~BUSAK: U10.a31 (31A), U15.18 (O0a)
/ECB_BUS/B_~BUSRQ: RN1.2 (R1), U10.a11 (11A), U15.17 (I3b)
/ECB_BUS/B_~HALT: U10.c25 (25C), U15.9 (O0b)
/ECB_BUS/B_~IEO: RN1.5 (R4), U10.c16 (16C)
/ECB_BUS/B_~INT: RN1.3 (R2), U10.c21 (21C), U15.13 (I1b)
/ECB_BUS/B_~IORQ: U10.a27 (27A), U13.10 (B1)
/ECB_BUS/B_~IRQ0: RN2.9 (R8), U10.b21 (21B), U16.17 (I3b)
/ECB_BUS/B_~IRQ1: RN2.8 (R7), U10.b20 (20B), U16.15 (I2b)
/ECB_BUS/B_~IRQ2: RN2.7 (R6), U10.b19 (19B), U16.13 (I1b)
/ECB_BUS/B_~IRQ3: RN2.6 (R5), U10.b18 (18B), U16.11 (I0b)
/ECB_BUS/B_~IRQ4: RN2.5 (R4), U10.b17 (17B), U16.8 (I3a)
/ECB_BUS/B_~IRQ5: RN2.4 (R3), U10.b16 (16B), U16.6 (I2a)
/ECB_BUS/B_~IRQ6: RN2.3 (R2), U10.b15 (15B), U16.4 (I1a)
/ECB_BUS/B_~IRQ7: RN2.2 (R1), U10.b14 (14B), U16.2 (I0a)
/ECB_BUS/B_~M1: U10.a20 (20A), U15.16 (O1a)
/ECB_BUS/B_~MREQ: U10.c30 (30C), U13.11 (B0)
/ECB_BUS/B_~RD: U10.c24 (24C), U13.8 (B3)
/ECB_BUS/B_~RESET: JP1.2 (C), U10.c31 (31C)
/ECB_BUS/B_~RESOUT: JP1.1 (A), U10.c26 (26C), U15.12 (O3a)
/ECB_BUS/B_~WAIT: RN1.4 (R3), U10.a10 (10A), U15.15 (I2b)
/ECB_BUS/B_~WR: U10.c22 (22C), U13.9 (B2)
A0: U11.2 (A0); also elsewhere on the board
A1: U11.5 (A3); also elsewhere on the board
A2: U11.7 (A5); also elsewhere on the board
A3: U11.6 (A4); also elsewhere on the board
A4: U12.3 (A1); also elsewhere on the board
A5: U12.4 (A2); also elsewhere on the board
A6: U12.5 (A3); also elsewhere on the board
A7: U11.3 (A1); also elsewhere on the board
A8: U11.4 (A2); also elsewhere on the board
A9: U12.8 (A6); also elsewhere on the board
A10: U12.2 (A0); also elsewhere on the board
A11: U11.8 (A6); also elsewhere on the board
A12: U12.7 (A5); also elsewhere on the board
A13: U12.9 (A7); also elsewhere on the board
A14: U11.9 (A7); also elsewhere on the board
A15: U12.6 (A4); also elsewhere on the board
D0: U14.2 (A0); also elsewhere on the board
D1: U14.9 (A7); also elsewhere on the board
D2: U14.6 (A4); also elsewhere on the board
D3: U14.7 (A5); also elsewhere on the board
D4: U14.8 (A6); also elsewhere on the board
D5: U14.3 (A1); also elsewhere on the board
D6: U14.5 (A3); also elsewhere on the board
D7: U14.4 (A2); also elsewhere on the board
DATA_DIR: U14.1 (A->B); also elsewhere on the board
IRQ0: U16.3 (O3b); also elsewhere on the board
IRQ1: U16.5 (O2b); also elsewhere on the board
IRQ2: U16.7 (O1b); also elsewhere on the board
IRQ3: U16.9 (O0b); also elsewhere on the board
IRQ4: U16.12 (O3a); also elsewhere on the board
IRQ5: U16.14 (O2a); also elsewhere on the board
IRQ6: U16.16 (O1a); also elsewhere on the board
IRQ7: U16.18 (O0a); also elsewhere on the board
VCC: C38.1, C39.1, C40.1, C41.1, C42.1, C43.1, C44.1, RN1.1 (common), RN2.1 (common), U10.a1 (1A), U10.b1 (1B), U10.c1 (1C), U11.20 (VCC), U12.20 (VCC), U13.14 (VCC), U14.20 (VCC), U15.20 (VCC), U16.20 (VCC); also elsewhere on the board
~BUSAK: U11.1 (A->B), U12.1 (A->B), U13.1 (OEa), U13.13 (OEb), U15.2 (I0a); also elsewhere on the board
~BUSRQ: U15.3 (O3b); also elsewhere on the board
~HLTA: U15.11 (I0b); also elsewhere on the board
~INT: U15.7 (O1b); also elsewhere on the board
~IORQ: U13.4 (A1); also elsewhere on the board
~M1: U15.4 (I1a); also elsewhere on the board
~MEMRQ: U13.3 (A0); also elsewhere on the board
~RD: U13.6 (A3); also elsewhere on the board
~RESET: U15.8 (I3a); also elsewhere on the board
~RESIN: JP1.3 (B); also elsewhere on the board
~WAIT: U15.5 (O2b); also elsewhere on the board
~WR: U13.5 (A2); also elsewhere on the board
Φ2(TTL): U15.6 (I2a); also elsewhere on the board

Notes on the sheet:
2-3 KONTRON PREFERRED
Copyright (C) 2025 Miroslav Sladek This documentation describes Open Hardware and is licensed under the CERN OHL v. 1.2. You may redistribute and modify this documentation under the terms of the CERN OHL v.1.2. (http://ohwr.org/cernohl). This documentation is distributed WITHOUT ANY EXPRESS OR IMPL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

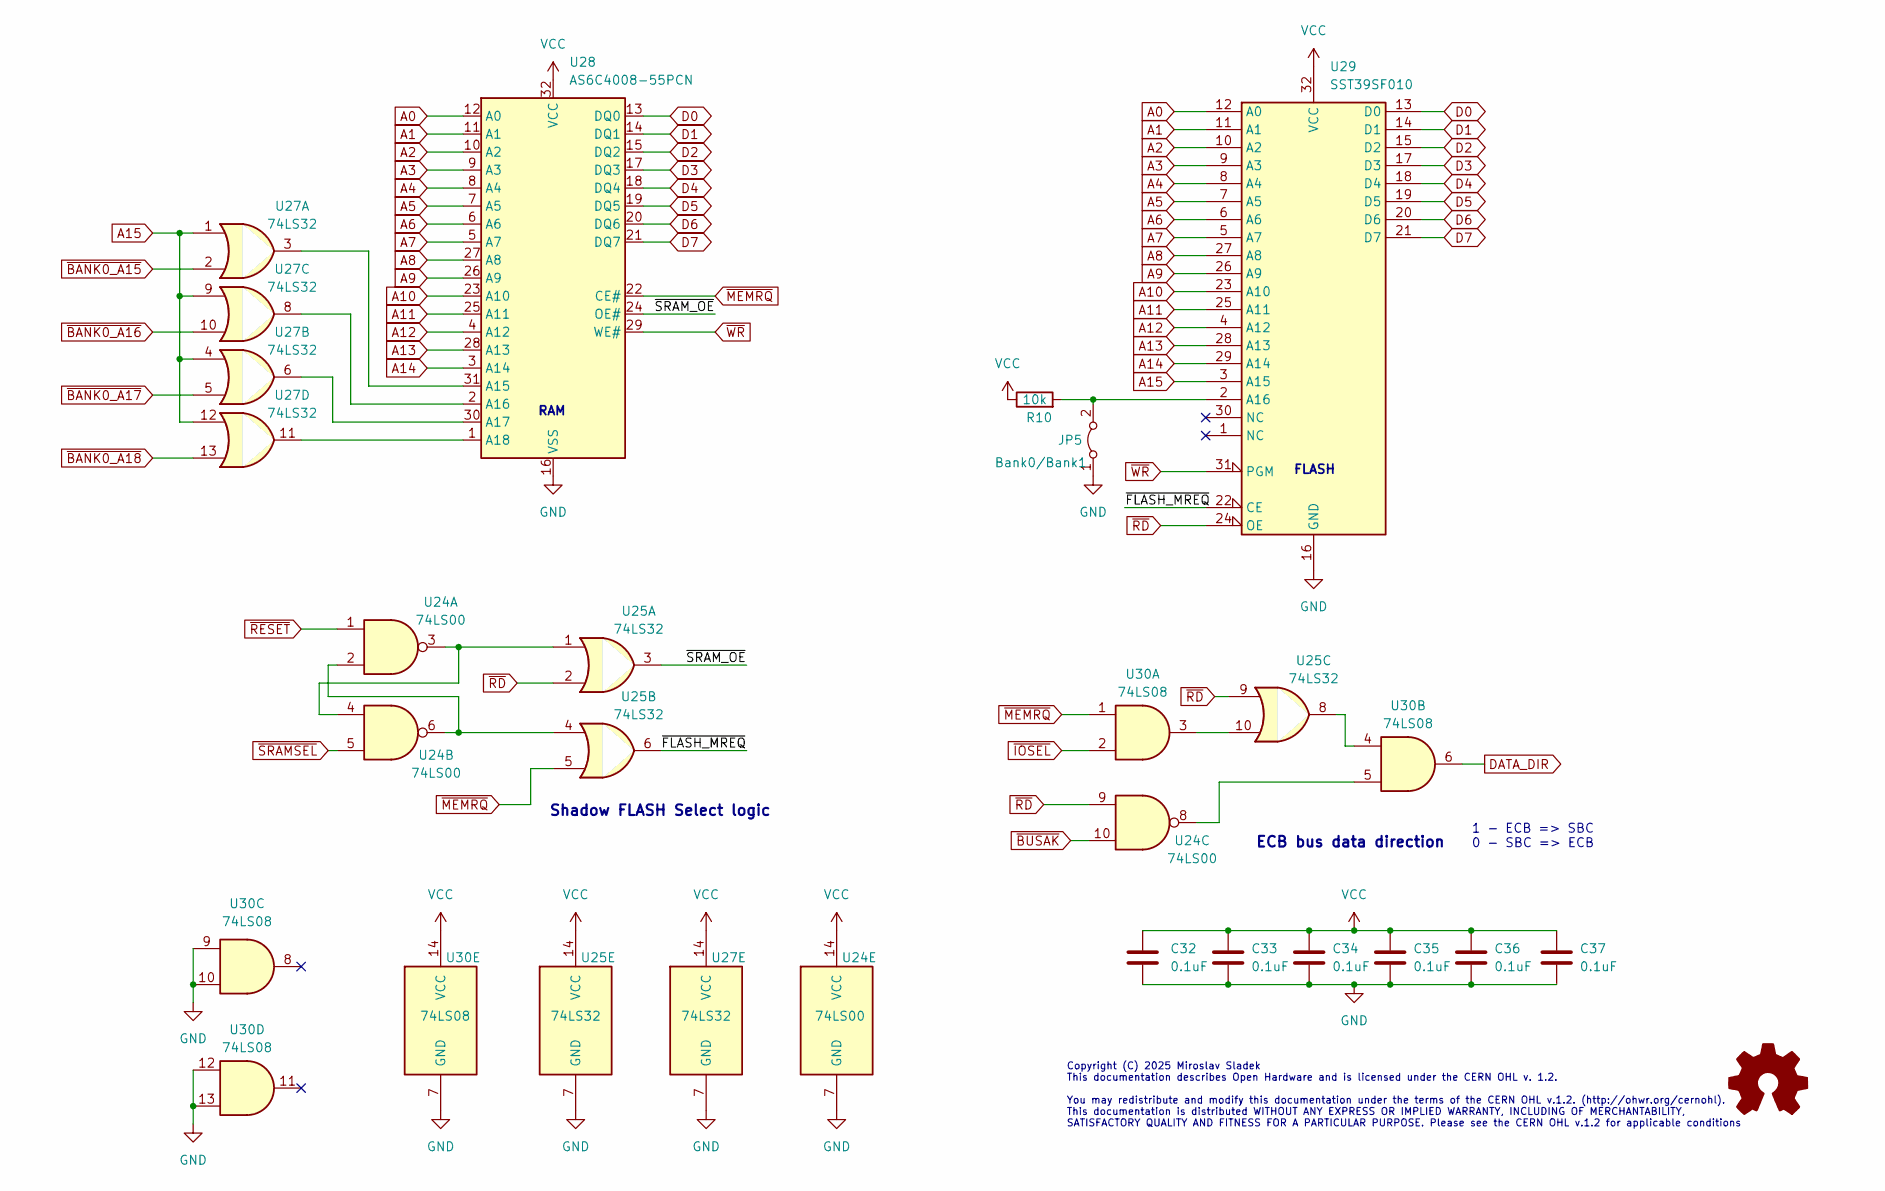
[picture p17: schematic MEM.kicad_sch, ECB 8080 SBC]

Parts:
C32, C33, C34, C35, C36, C37: 0.1uF; C_Disc_D4.3mm_W1.9mm_P5.00mm
JP5: Bank0/Bank1; PinHeader_1x02_P2.54mm_Vertical
R10: 10k; R_Axial_DIN0204_L3.6mm_D1.6mm_P7.62mm_Horizontal
U24: 74LS00; DIP-14_W7.62mm_Socket
U25, U27: 74LS32; DIP-14_W7.62mm_Socket
U28: AS6C4008-55PCN; DIP-32_W15.24mm_Socket
U29: SST39SF010; DIP-32_W15.24mm_Socket
U30: 74LS08; DIP-14_W7.62mm_Socket

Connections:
/MEM/~FLASH_MREQ: U25.6, U29.22 (CE)
/MEM/~SRAM_OE: U25.3, U28.24 (OE#)
A0: U28.12 (A0), U29.12 (A0); also elsewhere on the board
A1: U28.11 (A1), U29.11 (A1); also elsewhere on the board
A2: U28.10 (A2), U29.10 (A2); also elsewhere on the board
A3: U28.9 (A3), U29.9 (A3); also elsewhere on the board
A4: U28.8 (A4), U29.8 (A4); also elsewhere on the board
A5: U28.7 (A5), U29.7 (A5); also elsewhere on the board
A6: U28.6 (A6), U29.6 (A6); also elsewhere on the board
A7: U28.5 (A7), U29.5 (A7); also elsewhere on the board
A8: U28.27 (A8), U29.27 (A8); also elsewhere on the board
A9: U28.26 (A9), U29.26 (A9); also elsewhere on the board
A10: U28.23 (A10), U29.23 (A10); also elsewhere on the board
A11: U28.25 (A11), U29.25 (A11); also elsewhere on the board
A12: U28.4 (A12), U29.4 (A12); also elsewhere on the board
A13: U28.28 (A13), U29.28 (A13); also elsewhere on the board
A14: U28.3 (A14), U29.29 (A14); also elsewhere on the board
A15: U27.1, U27.4, U27.9, U27.12, U29.3 (A15); also elsewhere on the board
D0: U28.13 (DQ0), U29.13 (D0); also elsewhere on the board
D1: U28.14 (DQ1), U29.14 (D1); also elsewhere on the board
D2: U28.15 (DQ2), U29.15 (D2); also elsewhere on the board
D3: U28.17 (DQ3), U29.17 (D3); also elsewhere on the board
D4: U28.18 (DQ4), U29.18 (D4); also elsewhere on the board
D5: U28.19 (DQ5), U29.19 (D5); also elsewhere on the board
D6: U28.20 (DQ6), U29.20 (D6); also elsewhere on the board
D7: U28.21 (DQ7), U29.21 (D7); also elsewhere on the board
DATA_DIR: U30.6; also elsewhere on the board
unnamed: JP5.2 (B), R10.2, U29.2 (A16)
unnamed: U24.2, U24.6, U25.4
unnamed: U24.3, U24.4, U25.1
unnamed: U24.8, U30.5
unnamed: U25.8, U30.4
unnamed: U25.10, U30.3
unnamed: U27.3, U28.31 (A15)
unnamed: U27.8, U28.2 (A16)
unnamed: U27.6, U28.30 (A17)
unnamed: U27.11, U28.1 (A18)
VCC: C32.1, C33.1, C34.1, C35.1, C36.1, C37.1, R10.1, U24.14 (VCC), U25.14 (VCC), U27.14 (VCC), U28.32 (VCC), U29.32 (VCC), U30.14 (VCC); also elsewhere on the board
~BANK0_A15: U27.2; also elsewhere on the board
~BANK0_A16: U27.10; also elsewhere on the board
~BANK0_A17: U27.5; also elsewhere on the board
~BANK0_A18: U27.13; also elsewhere on the board
~BUSAK: U24.10; also elsewhere on the board
~IOSEL: U30.2; also elsewhere on the board
~MEMRQ: U25.5, U28.22 (CE#), U30.1; also elsewhere on the board
~RD: U24.9, U25.2, U25.9, U29.24 (OE); also elsewhere on the board
~RESET: U24.1; also elsewhere on the board
~SRAMSEL: U24.5; also elsewhere on the board
~WR: U28.29 (WE#), U29.31 (PGM); also elsewhere on the board

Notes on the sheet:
FLASH
ECB bus data direction
Shadow FLASH Select logic
1 - ECB => SBC 0 - SBC => ECB
RAM
Copyright (C) 2025 Miroslav Sladek This documentation describes Open Hardware and is licensed under the CERN OHL v. 1.2. You may redistribute and modify this documentation under the terms of the CERN OHL v.1.2. (http://ohwr.org/cernohl). This documentation is distributed WITHOUT ANY EXPRESS OR IMPL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

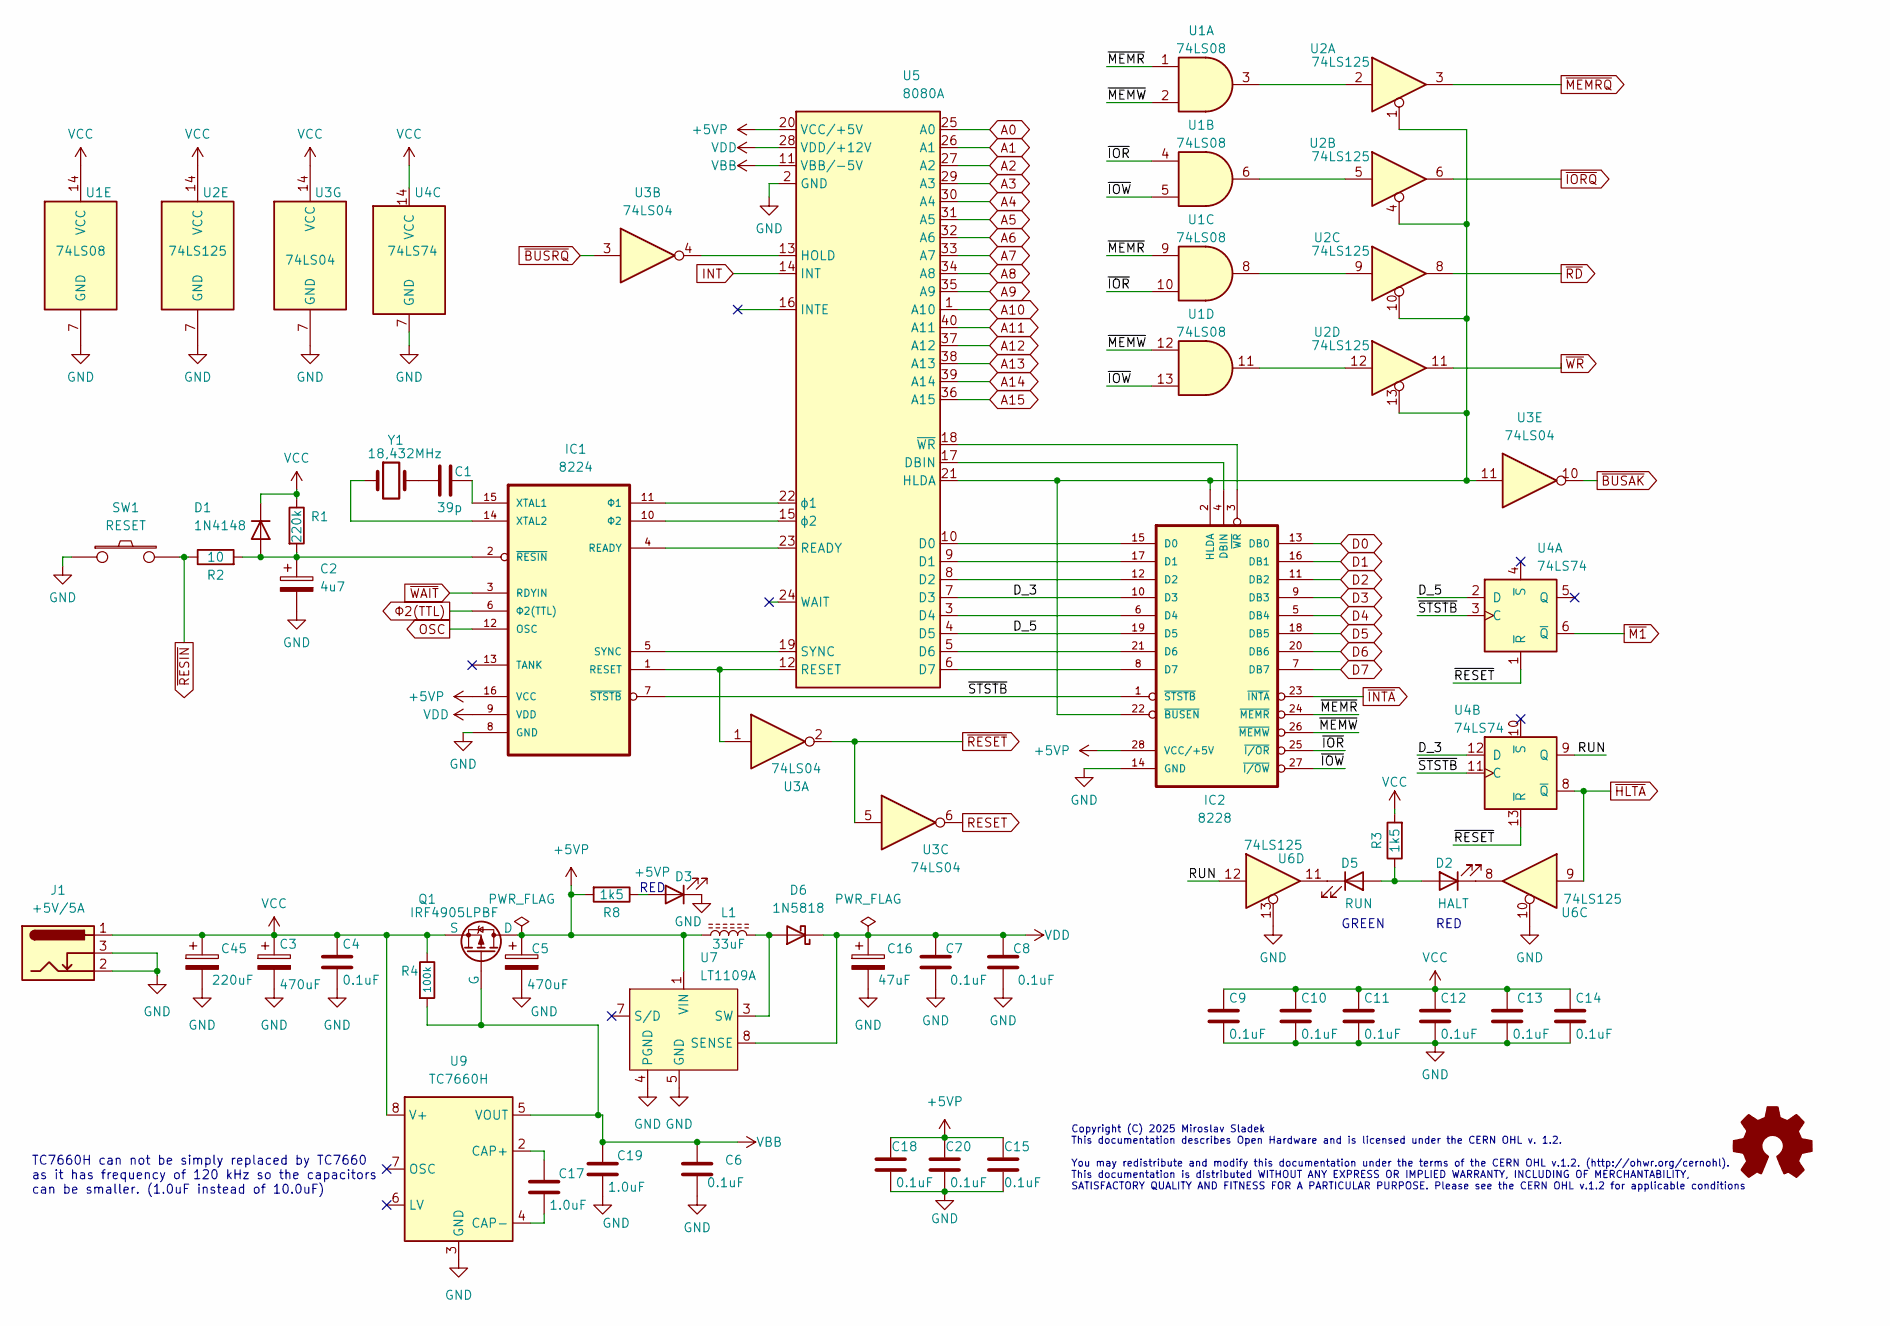
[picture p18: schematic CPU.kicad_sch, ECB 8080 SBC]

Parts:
C1: 39p; C_Disc_D5.0mm_W2.5mm_P2.50mm
C2: 4u7; CP_Radial_D4.0mm_P1.50mm
C3, C5: 470uF; CP_Radial_D6.3mm_P2.50mm
C4, C6, C7, C8, C9, C10, C11, C12, C13, C14, C15, C18, C20: 0.1uF; C_Disc_D4.3mm_W1.9mm_P5.00mm
C16: 47uF; CP_Radial_D5.0mm_P2.00mm
C17, C19: 1.0uF; C_Disc_D4.7mm_W2.5mm_P5.00mm
C45: 220uF; CP_Radial_D5.0mm_P2.00mm
D1: 1N4148; D_DO-35_SOD27_P7.62mm_Horizontal
D2: HALT; LED_D3.0mm
D3: +5VP; LED_D3.0mm
D5: RUN; LED_D3.0mm
D6: 1N5818; D_DO-41_SOD81_P10.16mm_Horizontal
IC1: 8224; DIP-16_W7.62mm_Socket
IC2: 8228; DIP-28_W15.24mm_Socket
J1: +5V/5A; 694106301002_1
L1: 33uF; L_Radial_D6.0mm_P4.00mm
Q1: IRF4905LPBF; TO254P483X1016X1501-3P
R1: 220k; R_Axial_DIN0204_L3.6mm_D1.6mm_P7.62mm_Horizontal
R2: 10; R_Axial_DIN0204_L3.6mm_D1.6mm_P7.62mm_Horizontal
R3, R8: 1k5; R_Axial_DIN0204_L3.6mm_D1.6mm_P7.62mm_Horizontal
R4: 100k; R_Axial_DIN0204_L3.6mm_D1.6mm_P7.62mm_Horizontal
SW1: RESET; PinHeader_1x02_P2.54mm_Vertical
U1: 74LS08; DIP-14_W7.62mm_Socket
U2, U6: 74LS125; DIP-14_W7.62mm_Socket
U3: 74LS04; DIP-14_W7.62mm_Socket
U4: 74LS74; DIP-14_W7.62mm_Socket
U5: 8080A; DIP-40_W15.24mm_Socket
U7: LT1109A; DIP-8_W7.62mm_Socket
U9: TC7660H; DIP-8_W7.62mm_Socket
Y1: 18,432MHz; Crystal_HC49-U_Vertical

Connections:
+5VP: C5.1, C15.1, C18.1, C20.1, IC1.16 (VCC), IC2.28 (VCC/+5V), L1.1, Q1.3 (D), R8.2, U5.20 (VCC/+5V), U7.1 (VIN)
/CPU/D_3: IC2.10 (D3), U4.12 (D), U5.7 (D3)
/CPU/D_5: IC2.19 (D5), U4.2 (D), U5.4 (D5)
/CPU/RUN: U4.9 (Q), U6.12
/CPU/~IOR: IC2.25 (~I/OR), U1.4, U1.10
/CPU/~IOW: IC2.27 (~I/OW), U1.5, U1.13
/CPU/~MEMR: IC2.24 (~MEMR), U1.1, U1.9
/CPU/~MEMW: IC2.26 (~MEMW), U1.2, U1.12
/CPU/~STSTB: IC1.7 (~STSTB), IC2.1 (~STSTB), U4.3 (C), U4.11 (C)
A0: U5.25 (A0); also elsewhere on the board
A1: U5.26 (A1); also elsewhere on the board
A2: U5.27 (A2); also elsewhere on the board
A3: U5.29 (A3); also elsewhere on the board
A4: U5.30 (A4); also elsewhere on the board
A5: U5.31 (A5); also elsewhere on the board
A6: U5.32 (A6); also elsewhere on the board
A7: U5.33 (A7); also elsewhere on the board
A8: U5.34 (A8); also elsewhere on the board
A9: U5.35 (A9); also elsewhere on the board
A10: U5.1 (A10); also elsewhere on the board
A11: U5.40 (A11); also elsewhere on the board
A12: U5.37 (A12); also elsewhere on the board
A13: U5.38 (A13); also elsewhere on the board
A14: U5.39 (A14); also elsewhere on the board
A15: U5.36 (A15); also elsewhere on the board
D0: IC2.13 (DB0); also elsewhere on the board
D1: IC2.16 (DB1); also elsewhere on the board
D2: IC2.11 (DB2); also elsewhere on the board
D3: IC2.9 (DB3); also elsewhere on the board
D4: IC2.5 (DB4); also elsewhere on the board
D5: IC2.18 (DB5); also elsewhere on the board
D6: IC2.20 (DB6); also elsewhere on the board
D7: IC2.7 (DB7); also elsewhere on the board
INT: U5.14 (INT); also elsewhere on the board
unnamed: C1.1, Y1.2
unnamed: C2.1, D1.2 (A), IC1.2 (~RESIN), R1.2, R2.2
unnamed: D2.2 (A), D5.2 (A), R3.1
unnamed: D2.1 (K), U6.8
unnamed: D3.2 (A), R8.1
unnamed: D5.1 (K), U6.11
unnamed: D6.2 (A), L1.2, U7.3 (SW)
unnamed: IC1.4 (READY), U5.23 (READY)
unnamed: IC1.1 (RESET), U3.1, U5.12 (RESET)
unnamed: IC1.5 (SYNC), U5.19 (SYNC)
unnamed: C1.2, IC1.15 (XTAL1)
unnamed: IC1.14 (XTAL2), Y1.1
unnamed: IC1.11 (Φ1), U5.22 (ϕ1)
unnamed: IC1.10 (Φ2), U5.15 (ϕ2)
unnamed: IC2.15 (D0), U5.10 (D0)
unnamed: IC2.17 (D1), U5.9 (D1)
unnamed: IC2.12 (D2), U5.8 (D2)
unnamed: IC2.6 (D4), U5.3 (D4)
unnamed: IC2.21 (D6), U5.5 (D6)
unnamed: IC2.8 (D7), U5.6 (D7)
unnamed: IC2.4 (DBIN), U5.17 (DBIN)
unnamed: IC2.2 (HLDA), IC2.22 (~BUSEN), U2.1, U2.4, U2.10, U2.13, U3.11, U5.21 (HLDA)
unnamed: IC2.3 (~WR), U5.18 (~WR)
unnamed: U1.3, U2.2
unnamed: U1.6, U2.5
unnamed: U1.8, U2.9
unnamed: U1.11, U2.12
unnamed: U3.4, U5.13 (HOLD)
unnamed: C17.1, U9.2 (CAP+)
unnamed: C17.2, U9.4 (CAP-)
OSC: IC1.12 (OSC); also elsewhere on the board
RESET: U3.6; also elsewhere on the board
VBB: C6.1, C19.1, Q1.1 (G), R4.2, U5.11 (VBB/-5V), U9.5 (VOUT)
VCC: C3.1, C4.1, C9.1, C10.1, C11.1, C12.1, C13.1, C14.1, C45.1, D1.1 (K), J1.1, Q1.2 (S), R1.1, R3.2, R4.1, U1.14 (VCC), U2.14 (VCC), U3.14 (VCC), U4.14 (VCC), U9.8 (V+); also elsewhere on the board
VDD: C7.1, C8.1, C16.1, D6.1 (K), IC1.9 (VDD), U5.28 (VDD/+12V), U7.8 (SENSE)
~BUSAK: U3.10; also elsewhere on the board
~BUSRQ: U3.3; also elsewhere on the board
~HLTA: U4.8 (~Q), U6.9; also elsewhere on the board
~INTA: IC2.23 (~INTA); also elsewhere on the board
~IORQ: U2.6; also elsewhere on the board
~M1: U4.6 (~Q); also elsewhere on the board
~MEMRQ: U2.3; also elsewhere on the board
~RD: U2.8; also elsewhere on the board
~RESET: U3.2, U3.5, U4.1 (~R), U4.13 (~R); also elsewhere on the board
~RESIN: R2.1, SW1.2; also elsewhere on the board
~WAIT: IC1.3 (RDYIN); also elsewhere on the board
~WR: U2.11; also elsewhere on the board
Φ2(TTL): IC1.6 (Φ2(TTL)); also elsewhere on the board

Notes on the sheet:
GREEN
RED
TC7660H can not be simply replaced by TC7660 as it has frequency of 120 kHz so the capacitors can be smaller. (1.0uF instead of 10.0uF)
Copyright (C) 2025 Miroslav Sladek This documentation describes Open Hardware and is licensed under the CERN OHL v. 1.2. You may redistribute and modify this documentation under the terms of the CERN OHL v.1.2. (http://ohwr.org/cernohl). This documentation is distributed WITHOUT ANY EXPRESS OR IMPL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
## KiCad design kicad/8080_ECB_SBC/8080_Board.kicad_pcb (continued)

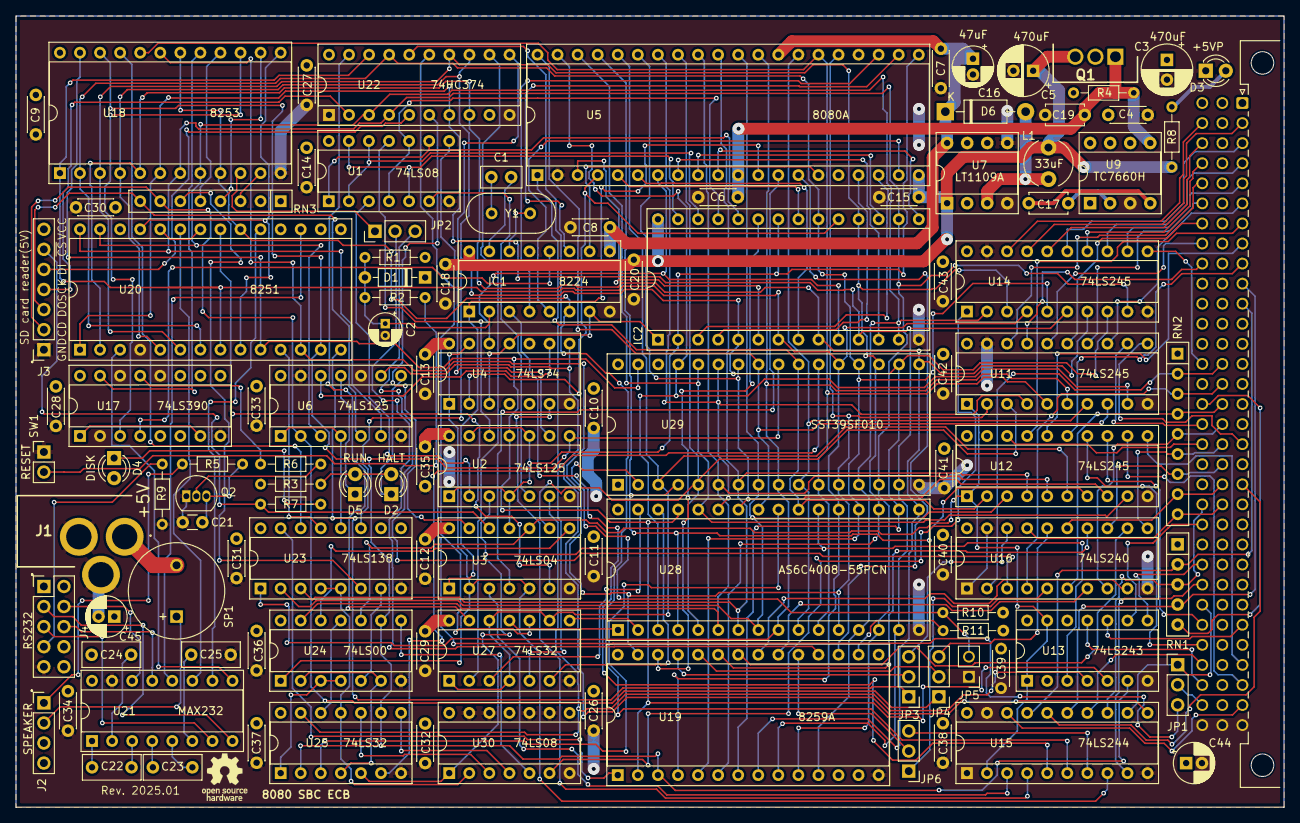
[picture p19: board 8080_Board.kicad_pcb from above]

Board: 2 copper layers, 160.5 x 100.2 mm, 111 parts (0 on the bottom side), 207 nets.

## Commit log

2025-04-20 Added pdf schematics.
2025-04-21 Added power supply information to README.md
